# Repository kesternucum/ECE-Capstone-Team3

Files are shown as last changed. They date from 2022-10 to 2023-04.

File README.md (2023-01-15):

# Parking Lot Monitoring System

## Executive Summary

Commuter students at Tennessee Technological University in Cookeville, TN, frequently face difficulties to find open parking spots in lots during peak hours of the school day, which causes tardiness to class to be a common occurrence. Commuters typically have a lack of foreknowledge of the availability of parking spots across lots prior to entering campus. Due to current products on the market either being very expensive or not fully feasible or effective for Tennessee Tech’s parking lots, an in-house parking lot monitoring system designed by students in Tennessee Tech’s College of Engineering was proposed to provide a more cost-effective solution. A parking lot monitoring system has been designed to utilize sensor technology to track and frequently update the number of available parking spots so that students can know the occupancy of a parking lot in real-time. The data from the sensor technology would be displayed on a mobile application that students can download to view real-time statistics and previous history of parking lot occupancy, as well as on a ground-level display board. This project involves interdisciplinary collaboration between teams from the Department of Electrical and Computer Engineering and the Department of Computer Science while under the direction of the Naval Sea Systems Command (NAVSEA) in Dahlgren, VA.

## Capabilities

As a proof of concept, this project is focused on implementing a Parking Lot Monitoring System to track the number of available parking spots in the Red lot behind Bell Hall. The goals for the capabilities of this system are:
  * Utilize computer vision AI to determine the number of available parking spots from images that are sent from cameras installed around the Bell Hall lot
  * Track the number of cars inside the Bell Hall lot using pneumatic road tubes for validation of the measurements from the cameras and computer vision
  * Display the number of available parking spots on a mobile application that students can use
  * Display the number of available parking spots on a sign (similar to those at airport parking lots)

## Salient Outcomes

The most important outcomes of this project will be added here once the Parking Lot Monitoring System project has been implemented and tested.

## Project Demonstration & Images

A demonstration video and images of the project will be added here once the system has been implemented and tested.

## About Us

### Team

**Kester Nucum** is a senior Computer Engineering major at Tennessee Technological University with double minors in Music Performance and Honors. Kester's interests in Electrical and Computer Engineering include artificial intelligence, digital signal processing, and applications in radar and RF technology. He has spent two summers as an intern at Dynetics in Huntsville, AL, where he worked in modeling and simulation of foreign weapons threat systems, and he plans to obtain a Master's Degree in ECE prior to starting a career in the defense industry. For the Parking Lot Monitoring System project, Kester will be primarily focusing on the cameras in the primary data acquisition system, the hardware for the server, and the computer vision AI software. Outside of classes, Kester serves as the President of the Tennessee Gamma chapter of Tau Beta Pi, plays violin in the University Orchestra, and is active in University Catholic.

**Aaron Wilhite** is a senior Electrical Engineering major at Tennessee Technological University with a minor in Math. He spent the previous year at a co-op with EOSYS in Smyrna, TN doing custom system integration. During this co-op he gained experience in HMI design and PLC (Programmable Logic Controller) programming. For the Parking Lot Monitoring System project, Aaron will be primarily focusing on the sign subsystem. Outside of classes, Aaron spends most of his time rock climbing and camping.

**Gabriel Laboy** is a senior Computer Engineering major with a minor in Computer Science at Tennessee Technological University. His interests include digital systems, virtual reality (VR), and cyber security. He spent a whole year as a co-op at EOSYS located in Smyrna, TN, and later plans to pursue a Master's Degree in Computer Science in hopes of being a professor of university. Gabriel's role in the project will be working on the power for the primary data acquisition system and collaboration with the Computer Science (CSC) team to ensure successful operation of the mobile application with the server. He is also currently serving as the Vice Chair of the student chapter of the Institute of Electrical and Electronics Engineers (IEEE), and will serve as the Recording Secretary of the Tennessee Gamma chapter of Tau Beta Pi in the spring.

**Genevieve Schreiber** is a senior Computer Engineering major at Tennessee Technological University with a minor in Mathematics. Her interests involve FPGAs, embedded systems, and space. She has spent 1 year interning at ALTEN as a software intern working in embedded systems. She plans to work in space-adjacent fields post-graduation. For this Parking Lot Monitoring System, Genevieve will be primarily focused on the networks involved between the many devices used. She is also part of the Omega Phi Alpha national service sorority.

**Reggie Garza** is a senior electrical engineering major at Tennessee Tech University. Reggie's interest include robotics and automation. He has spent the last two years interning at ATC Automation in Cookeville,TN. There he has been part of a team of engineers and has contributed with the electrical design and programming of several machines. Reggie will be helping design the primary acquisition system and the secondary acquisition system.

### Faculty Supervisor

**Jesse Roberts** is a Lecturer in the Department of Electrical and Computer Engineering at Tennessee Technological University. He received both his Bachelor's and Master's Degrees in Electrical Engineering from Tennessee Tech, and he is currently working on obtaining his Doctorate of Philosophy in Computer Science from Vanderbilt University, anticipated May 2023. He is the instructor for the ECE 4961 Capstone I and ECE 4971 Capstone II courses at Tennessee Tech, and he serves as the faculty supervisor for the Parking Lot Monitoring System project. His research interests include Game Theory and Mechanism Design, Graph and Learning Theory, Spiking Neural Networks, Computational Sustainability, Computational Creativity and Criticism, and Automation. In his free time, Jesse loves to go rock climbing.

### Stakeholders

The **Naval Surface Warfare Center Dahlgren Division** in Dahlgren, VA, under the Naval Sea Systems Command, more commonly referred to as **NAVSEA**, is the primary customer of this project. The NSWC Dahlgren Site is a premier research and development center that serves as a specialty site for weapon system integration. Engineers and scientists focus on providing research, development, test and evaluation, analysis, systems engineering, integration, and certification of complex naval warfare systems related to surface warfare and strategic systems. NAVSEA engineers, builds, buys and maintains the ships, submarines, carriers (unmanned systems) and combat systems that patrol the oceans and secure American shores.

The major stakeholder that will be affected by this project are the **commuter students** of Tennessee Tech since this project is designed with them in mind. We hope that this project will help commuter students (students who drive to campus and possess a Red parking pass) plan out their parking routines more effectively and also know of alternate spots to park on campus, albeit if those spots are more inconvenient/out of the way.

Another major stakeholder is **Tennessee Tech** itself because the data collected from this system--the parking history of lots throughout the day--can be potentially used for future planning and zoning purposes. This data can prove to be valuable in collecting data about student parking behaviors since campus parking is an evergreen problem that persists at Tennessee Tech.

### Recognitions

We first would like to thank Kristen Voyles and Rob Sexton at NSWC Dahlgren for their mentorship about the engineering design process throughout the entire capstone process. Their feedback and advice were invaluable, not just for the project but for us as future engineers as well.

We would like to thank the Office of Parking and Transportation, University Police, and Facilities at Tennessee Tech for allowing to implement this project on campus. More recognitions to come!

Also, thank you to WUCT - News Talk 94.1/AM 1600 for featuring our project on your station! We are excited that the community is excited about our project. Go check out the news article here: ["TTU Capstone Students Working To Develop Program To Better Parking"](https://newstalk941.com/ttu-capstone-students-working-to-develop-program-to-better-parking/).

## Repo Organization

### Reports

All reports about the project holistically can be found in the [Reports](/Reports) folder. The major files in the Reports section are as follows:

1. [Project Proposal](/Reports/ProjectProposal.pdf)
2. [Conceptual Design and Planning](/Reports/Conceptual&#32;Design&#32;and&#32;Planning.pdf)
3. Final Report (to be added later)
4. Lessons Learned (to be added later)
5. Experimentation (to be added later)

### Documentation

All signoffs, electrical schematics, 3D models, and bill of materials (BOM) and other documentation such as images, the project datasheet, and project poster can be found in the [Documentation](/Documentation) folder. The major folders in the Documentation section are as follows:

1. [Signoffs](/Documentation/Signoffs)
  * Signoffs are written for each subsystem in which each subsystem's design is analyzed in light of the constraints to ensure their functionality prior to ordering their components. Signoffs once approved will be stored here.
2. [Electrical](/Documentation/Electrical)
  * The Electrical folder will contains two folders: [PCB](/Documentation/Electrical/PCB) and [Schematics](/Documentation/Electrical/Schematics). The PCB folder contains all designs for printed circuit boards (PCBs) that are custom built for this project. The Schematics folder contains all buildable wiring schematics for analog circuits designed for this project.
3. [Images](/Documentation/Images)
  * Images for the project, such as images of the project when built, images used for signoffs, etc.
4. [3D Models](/Documentation/3D&#32;Models)
  * Buildable 3D model schematics for each constructed system of the project.
5. Final Bill of Materials (to be added later)
  * All components ordered compiled to generate the total cost for building this project.
6. Datasheet (to be added later)
  * The datasheet includes all information necessary for other systems to interface with your project in the intended manner, such as the power expectations, interfacing, and compliance. The datasheet will also include results from all experimentation and the interpretation of the results.
7. Poster (to be added later)
  * Poster that is presented at the finale of Capstone II.

### Software

All software that has been programmed for this project will be stored in the [Software](/Software) folder.

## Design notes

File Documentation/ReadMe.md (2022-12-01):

# What should be in the documentation folder

## Signoffs

An important part of engineering is analysis. Designs must be analyzed to show that the subsystem is **likely** to function (sometimes things still don't work). This reduces the overall risk that a client or firm will have wasted money on a solution that was destined to fail. For information about what must be included in each signof file, refer to the readme file in the signoff directory.

A signoff must be completed and approved for each subsystem before the components for the subsystem may be ordered. Each of the signoff documents should be an appropriately named markdown file in the signoff directory.

## Final set of prints (final design artifacts)

All schematics and artifacts should be in an appropriate file type.

### 3D Models

Required format:
- .stl

3D models should be stored in the proper file type to facilitate editing, viewing, and printing. The best filetype for this is .stl, so all 3d models should be pushed to the repo as stl files. Stl files can be converted to solidworks models or autocad 3d models as necessary, can be 3d printed easily, and are 3d viewable natively in github. File (Documentation/3D Models)

Every constructed system of the project must have a complete (buildable) 3d model schematic.

### Wiring Schematics

Required software:
- autocad or autocad electrical

For wiring schematics, use autocad or autocad electrical. All the source files must be included in the github repo along with pdf versions of all schematics. File (Documentation/Electrical/Schematics/Sources)

Every electrical system must have a complete (buildable) pdf circuit schematic. File (Documentation/Electrical/Schematics)

Autocad is freely available to students with versions for mac, windows, and linux.

#### PCB files

Required Software:
- kicad

KiCad should be used for all PCB design. All source files must be deposited in the repo. File (Documentation/Electrical/PCB/Sources)

Along with the source files, a complete set of gerber files for each PCB must also be included in the repo. These should be included in a folder called gerber files. File (Documentation/Electrical/PCB)

kiCad is a free and open source software.

## Final BOM

The final version of the BOM should be uploaded as a pdf output of the excel BOM file. The excel BOM file should also be included.

## Datasheet

This must give all the information necessary for other systems to interface with your project in the intended manner. This must include the power expectations, interfacing, and compliance.

This must also include the results from all experimentation and the interpretation of the results.

## The project poster

Include the project poster

## Detailed photos of the project

Include a folder of a set of detailed photos of the project. File (Documentation/Images)

## Any additional documents that are appropriate to include

If there are additional items that are important to understanding and working on or with the project, include them as well.

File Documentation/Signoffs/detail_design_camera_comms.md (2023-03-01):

# Camera Communications Detail Design

## Function of Subsystems

The camera communications subsystem allows each camera to connect to the university's Wi-Fi network so that the images collected from each camera can be transmitted wirelessly to the remote server for AI image processing.

## Constraints

1. The Avigilon cameras have only Ethernet (RJ45) inputs and therefore require an adapter to connect to the Wi-Fi network, so the chosen adapter must be able to communicate back and forth between Ethernet (RJ45) and Wi-Fi.

2. This device must have the ability to establish a reliable and stable wireless connection to the Wi-Fi network in Bell Hall from its camera position. This device should be able to connect to Wi-Fi at a range of 100 m, which is the distance from Bell Hall to the southeast corner of the parking lot.

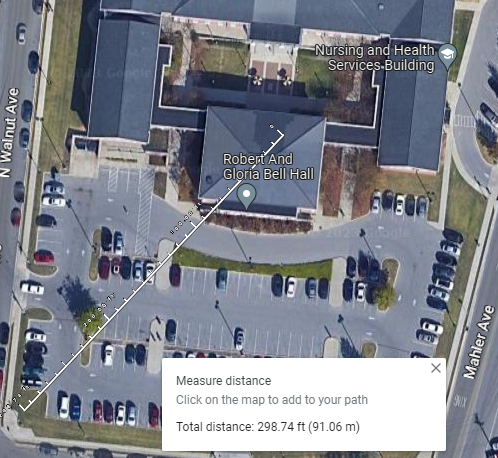
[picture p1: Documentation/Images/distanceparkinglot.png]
Figure 1. Distance Measurement between Cameras and Building
 

3. This device must be able to transmit frames at a resolution of 1080p (the resolution of the Avigilon cameras) at a frame rate of 30 fps (the rate of the Avigilon cameras). To stream a YouTube video at a 1080p resolution with a standard frame rate of 30 fps, a bitrate setting of 8 Mbps is recommended [1]. Thus, the Ethernet-to-WiFi converter adaptor must be able to transmit data at a rate of at least 8 Mbps.

# Buildable Schematic

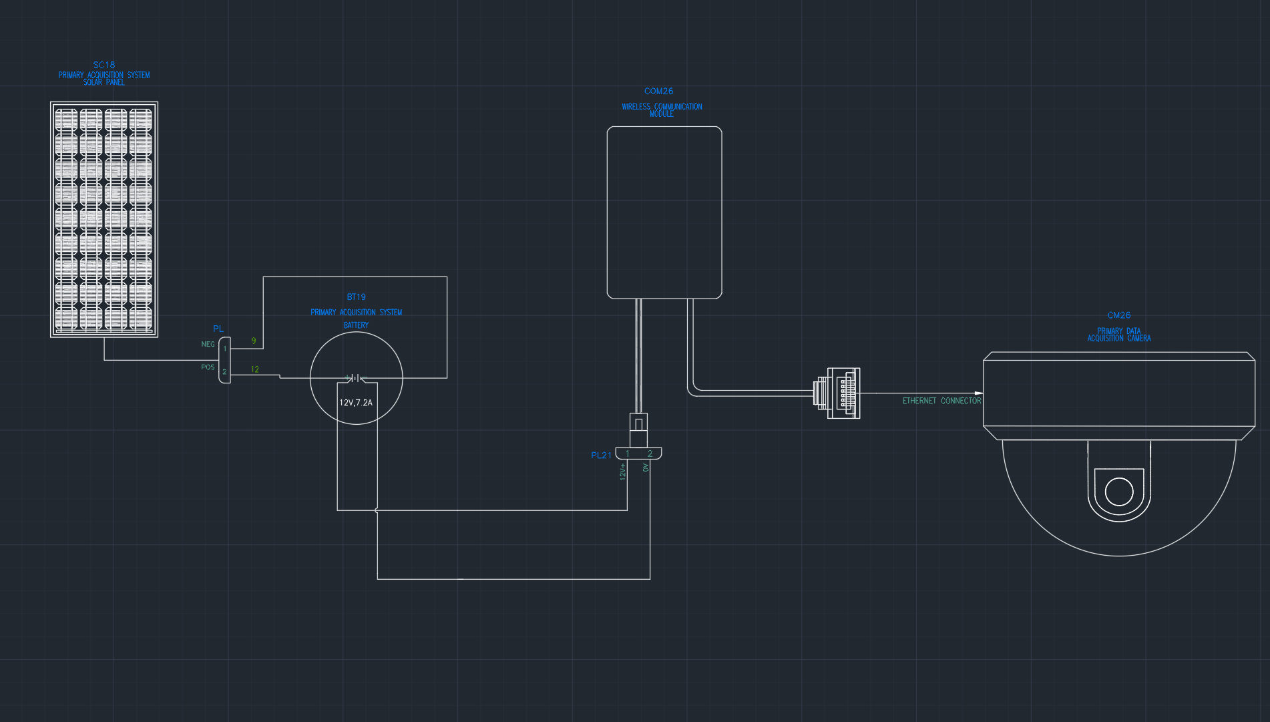
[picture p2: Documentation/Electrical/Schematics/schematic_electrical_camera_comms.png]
Figure 2. Wiring Diagram for Vonets VAP11G-50 Wi-Fi Bridge/Repeater


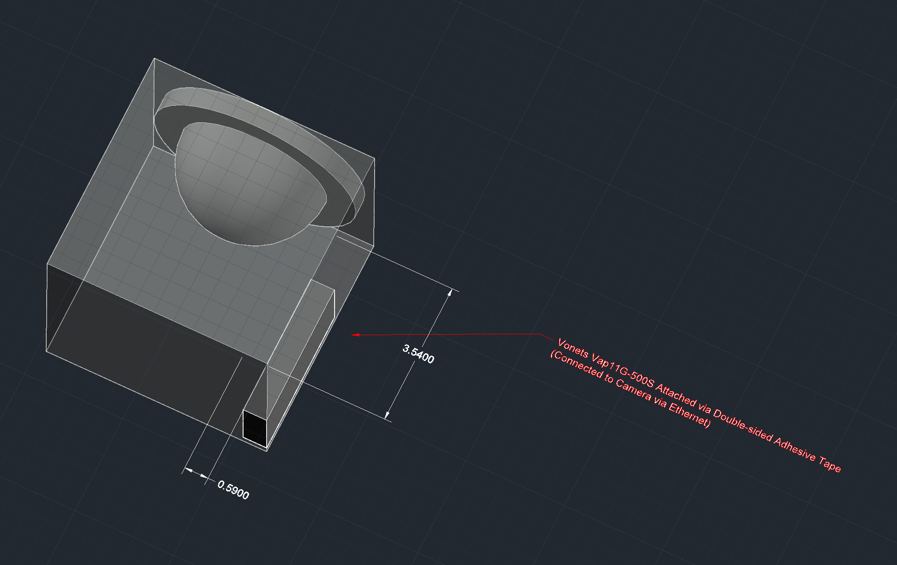
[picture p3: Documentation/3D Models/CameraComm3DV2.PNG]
Figure 3. Camera Communications 3D Schematic

<div align="center"> Figure 3. Camera Communication Module 3D Placement Schematic
<br />
<div align="left">

Note: The Module will be attached to the interior of the casing using a double sided adhesive tape.

## Analysis

Selected Adapter: Vonets VAP11G-500S Wi-Fi Bridge/Repeater

1. Ethernet-to-WiFi Adaptor
  - The VAP116-500S Wi-Fi Bridge/Repeater has an ethernet cable that can be connected to the Avigilon cameras (which can either be used for power over ethernet or transmission via ethernet, if no power is available).

2. Network Capabilities
  - The device has a transmission rate of 300 Mbps, which is well above the needed streaming rate of 8 Mbps.

3. Range
  - The ethernet-to-WiFi converter has a unobstructed range of 200 m unobstructed and obstructed of 100 m, which are both well-above the maximum range of 85 m needed to reach routers in Bell Hall.

## Bill of Materials

| Name of Item | Description | Used in which subsystem(s) | Part Number | Manufacturer | Quantity | Unit Price | Total |
| --- | --- | --- | --- | --- | --- | --- | ----- |
| VONETS VAP11G-500S WiFi to Ethernet Converter | WiFi Bridge 2.4GHz WiFi Repeater/Point to Point with RJ45 Male DC/USB Powered for PLC IP Camera Printer Medical Devices Network Device | Primary Data Acquisition | VAP11G-500S | Vonets | 2 | $37.98 | $37.98 |
| | | | | | | | **$75.96** |

Link to Purchase: [Purchase Link](https://www.amazon.com/%E3%80%90Upgraded-VAP11G-500S-Industrial-High-Power-Application/dp/B0B8ND6MQL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)
 
## Cited Sources

[1] [https://golightstream.com/what-is-video-bitrate/](https://golightstream.com/what-is-video-bitrate/)

# Revisions

2/15/2023 - Reformatted and reworked sign off with different Ethernet-to-WiFi adaptor

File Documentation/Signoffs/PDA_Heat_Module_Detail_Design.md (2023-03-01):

# Primary Data Acquisition Heat Module Detail Design

## Big Picture

The primary data acquisition will use cameras designed for indoor use, but in an outdoor setting. Therefore, a few more additional constraints must be addressed in order to ensure the cameras don’t malfunction during operation. This document addresses temperature control of the cameras to ensure the camera’s specified operation temperature is not exceeded.

## Specifications

Existing Hardware Constraints

1. Avigilon Cameras [1]
    * Operating Temperature: -10 °C to +50 °C (14 °F to 122 °F)

Reliability Constraints

1. Any device installed should last long enough to not require frequent replacement
2. Installed devices should not interfere with camera vision and operation
3. The temperature control element should only operate when the appropriate environmental temperature has been reached

## Buildable Schematic

Heat_Module_Connections

Figure 1. Hardware Electrical Connections

## Analysis

Environmental Temperatures

1. The average range of temperature within Cookeville for the year usually goes between 28 °F to 88 °F with it rarely going lower than 12 °F and higher than 94 °F [2]. The lowest and highest temperature ever recorded in Cookeville are -22 °F and 105 °F, respectively [3]. This means there is no concern for cooling the cameras given it has a max operating temperature of 122 °F, but they must be warmed up in the winter due to the minimum operating temperature of 14 °F [1].

Collecting Temperature Data

1. In order to get the current temperature, it has been decided to get information via a local weather station in Cookeville, TN. The server subsystem will get the temperature and send it to an Arduino Nano 33 IoT. This Arduino is capable of connecting to WiFi [4], so it should be able to receive information from the server once connected. The Arduino is also small (45 x 18 mm) and lightweight (5 g) [4], so it should not occupy a significant amount of space within the primary data acquisition system casing.

Heating the Environment

1. To heat the environment around the camera, it has been decided to go with a film heating plate. The films can reach temperatures of up to 80 °C (176 °F) [6] which should be plenty of heat to keep the surrounding environment of the camera warm. They are also small (30 x 40 mm) and lightweight (0.634 oz), and feature an adhesive side [6] which should make attachment to the casing of the primary data acquisition system simple.

Powering the Heating Element

1. To make sure that the heater plate only provides heat when needed, there will be a connection made between one of the Arduino digital pins and the heat plate mediated by a transistor. The transistor will act as a switch allowing power to be delivered to the heat plate from the power supply as seen in Figure 1 of the buildable schematic section. The Arduino will be programmed to source voltage to the transistor from its digital pin when a cold enough is read and keep sourcing voltage to the transistor for one minute before shutting off the digital pin. After a two minute delay, the Arduino will check the temperature again and repeat the powering process if needed.
2. The chosen transistor is an N-MOS transistor with the needed features to be compatible with both the Arduino and power supply.
    * A VDSS of 55 V and 47 A [8] which is far above the 5 V and 200 mA requirement to power the heat plate [6].
    * A VGS(th) of 1 V [8] which should meet the constraint of the 1.8-3.3 V output of the Arduino digital pin [5].

Addressing Risks

1. Condensation is a major concern given that the heating element will get very hot and operate around freezing temperatures. Proper ventilation of the primary data acquisition casing, though, will be handled by the ME team.
2. Protection of the arduino and heating plate from the weather will be handled in the casing subsystem design.

Important Notes

1. The BoM does not accurately reflect what will be purchased, but instead how much the system would need given the original outline of the project.

## Bill of Materials

| Name of item | Description | Subsystem | Part Number | Manufacturer | Quantity | Price | Total |
|---|---|---|---|---|---|---|---|
|Arduino Nano| Arduino Nano 33 IoT | Primary Data Acquisition | ABX00027 | Arduino | 7 | $24.00 | $168.00 |
|Transistor| MOSFET N-CH 55V 47A | Primary Data Acquisition | IRLZ44NPBF-ND | Infineon Technologies | 7 | $1.52 | $10.64 |
|Film Heater Plate| 5V 1W Flexible Polymerize Heater Film Stripboard Mat 30mmx40mm | Primary Data Acquisition | Number Not Found | Icstation | 2 | $15.99 | $31.98 |
| Total | | | | Total Components | 16 | Total Cost | $210.62 |

## Revisions

**02/11/2023**

Updated constraints requirement.

Removed invalid buildable schematic.

Changed method of temperature detection.

Created a Bill of Materials.

**02/20/2023**

Updated analysis to detail how the subsystem will get weather status.

Updated analysis to address being able to power the heat module.

Changed device used to communicate to server and power on heating element.

Update Bill of Materials.

**02/28/2023**

Updated big picture to more accurately reflect intent of design.

Updated constraints to more accurately reflect intent of design.

Updated analysis to make it more readable and added electrical analysis.

## Cited Sources

[1] “2.0 Megapixel Day/Night H.264 HD Indoor Dome Camera,” _AVIGILON_, 2013.  https://www.securityinformed.com/datasheets/avigilon-2-0-h3-d1-ip-dome-camera/co-3126-ga/2.0-H3-DdatasheetEN2.pdf.

[2] “Climate and Average Weather Year Round in Cookeville,” _Weather Spark_, 2023. https://weatherspark.com/y/15151/Average-Weather-in-Cookeville-Tennessee-United-States-Year-Round.

[3] “Cookeville Weather Records,” _Extreme Weather Watch_, 2022. https://www.extremeweatherwatch.com/cities/cookeville.

[4] “Arduino Nano 33 IoT,” _Arduino Store_, 2023. https://store-usa.arduino.cc/products/arduino-nano-33-iot.

[5] “V[oltage on digital output pins depending on voltage source?](https://forum.arduino.cc/t/voltage-on-digital-output-pins-depending-on-voltage-source/686526),” _Arduino Forum_, Dec 2020. https://forum.arduino.cc/t/voltage-on-digital-output-pins-depending-on-voltage-source/686526/2.

[6] “4 PCS Film Heater Plate Adhesive Pad, Icstation PI Heating Elements Film 5V 1W Flexible Polymerize Heater Film Stripboard Mat 30mmx40mm,” _amazon.com_, 2023. https://www.amazon.com/5V-Flexible-Polyimide-Heater-Plate/dp/B0727X2DGC/.

[7] “IRLZ44NPBF,” _Digi-Key_, 2023. https://www.digikey.com/en/products/detail/infineon-technologies/IRLZ44NPBF/811808.

[8] “IRLZ44NPbF,” _International Rectifier_, 11 Nov 2003. https://www.infineon.com/dgdl/irlz44npbf.pdf?fileId=5546d462533600a40153567217c32725.

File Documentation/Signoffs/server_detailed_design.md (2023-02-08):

# Detailed Design for Hardware of Server

## Function of the Subsystem
The server can be likened to the heart of the entire parking lot monitoring system, in which the server receives input data from the sensors, processes the data, and then send the data to be stored in a Firebase remote server. The server communicates with the Primary and Secondary Data Acquisition Systems, and it will have an AI application to process images from the Primary Data Acquisition System cameras to determine the number of cars in the parking lot. The server will also have a program to store the count from the road tubes in the Secondary Data Acquisition system, determine the accuracy of the counts between the Primary and Secondary systems, and calculate parking histories and averages.

## Constraints

Many of these constraints were determined first by researching the hardware needed for a full-scale surveillance system with 7 cameras (which will constantly provide video feed) and by determining the computational costs and speed to optimally run a computer vision image processing application that is adequate for our needs. However, a surveillance system requires much more processing power than what we need, so a surveillance system is treated as an ideal for our system.

In addition, the server will be designed to use the YOLO object detection algorithm. The YOLO (You-Only-Look-Once) Algorithm is a popular real-time object detection algorithm that is used in vehicle detection applications such as [1]. YOLO is a deep learning-based approach that can predict an object's class/category (what kind of object is it), bounding box (a box that encompasses the object), and probability inside bounding box, for multiple objects in a frame [2]. YOLOv4 is the latest version of the algorithm, featuring many improvements from its predecessor versions. Although YOLO is known for its high performance, it is very resource-intensive since it does run a deep neural network. On an AMD Ryzen 7 CPU on the Windows platform, YOLO only produces an image processing rate of 2.5 fps, but on a Nvidia GPU in the Linux platform, YOLO can process up to 45 fps [1]. Because the mobile application must update data at a minimum of every second (since this rate will provide enough of a real-time feel to users), the 5 cameras that track the statically tracked lots will only have one processed image every minute. For the dynamically tracked lots, since a minimum image rate of 5 fps is needed to capture at least 2 or 3 images to capture a moving car's motion and determine its direction (edge case is a fast-moving car at 25 mph), each of those cameras will send 5 images to the server per second, i.e. every 6th image. Thus, 5 cameras sending 1 image every minute with 2 cameras sending 5 images per second makes a minimum of 15 images to be processed within a second. The YOLO algorithm will be run on the GPU and primarily influence GPU constraints.

There are two frameworks that will either be used to run the YOLO algorithm. The first is OpenCV, which is a free, open-source library for computer vision applications that has been used extensively throughout industry. It is known for its high performance (as compared with other frameworks like TensorFlow) and its extensive documentation, providing a relatively easy learning experience for beginners. The hardware requirements for OpenCV are listed as according to their influence on certain computer parts. OpenCV (3.4.2 at minimum) has options to use enable CUDA for faster YOLO performance with GPU acceleration, though OpenCV is primarily CPU intensive [3]. The other framework is Darknet, which was made specifically for YOLO but runs only on Linux [4]. Darknet can also be used with OpenCV and CUDA dependencies as well. The computer components will be selected based off being able to support either of these frameworks, which should have similar constraints.

The server must also be able to run the Linux operating system due to the versatility of Linux as compared with Windows or MacOS for the needed programming power with the video feeds and AI applications.

1. CPU
  * The processor must be powerful enough to perform tasks such as determining the number of vehicles present in a parking lot via AI analyzing images sampled from multiple cameras and via keeping track of counts from road tubes and compiling statistical data and history about parking availability. For a surveillance system, it is recommended to have one thread per camera, which for this system means 7 threads (which can be provided in 4 double-threaded cores). Thus, the CPU needs at least 6 double-threaded cores which allows half of the threads to be devoted to obtaining images from the cameras and the other half for processing the images, processing road tube counts, and sending the processed data to the server. For live streaming applications, a frequency of 3.0 GHz is required for 1080p streaming (1080p is the intended resolution of the camera feeds) [5].
  * OpenCV can be run a laptop with a processor as "low" as an Intel Core Duo with a frequency of 1.83 Hz paired with 2 GB of RAM [6]. Since the YOLO algorithm will run primarily on the GPU, [6] provides a minimum baseline of what OpenCV needs to run, which is a minimum of 2 cores each with 1 thread. However, [3] tested YOLOv4 with CUDA-enabled OpenCV on a computer with an Intel Core i5 7300HQ CPU and a Nvidia GTX 1050 Ti GPU, and although the i5 7300HQ produced only 2.1 fps, the CPU for our system must match or exceed the performance of this CPU.

2. GPU
  * Since GPUs are typically used for AI/deep learning applications, the GPU will be mainly used to run the computer vision algorithm that processes the images from the cameras.
  * To run the YOLO algorithm, a Nvidia GPU is needed. [3] tested YOLOv4 with CUDA-enabled OpenCV on a computer with an Intel Core i5 7300HQ CPU and a Nvidia GTX 1050 Ti GPU. Running on the i5 7300HQ produced only 2.1 fps whereas the GTX 1050 Ti produced 20.1 fps. Thus, the GPU must match or exceed the performance of a GTX 1050 Ti.

3. RAM
  * It is recommended to have at least 4 GB RAM to run the OpenCV AI library [8]. In addition, for a surveillance system, 16 GB of RAM is recommended for 8-10 cameras [9]. However, because we are not live streaming, 16 GB should be sufficient for image collection and processing using the OpenCV AI library.

4. Storage
  * For the storage, two different storage drives are needed to ensure the highest efficiency when storing collected data and system data. A small SSD (128 GB) shall be used to store the boot of OS, which has been determined to be Linux, to increase the speed of the server. This is considered good practice for PCs/servers. In addition, since no images are being stored on the server, the server does not need a lot of storage, so 2 TB should be sufficient.

5. Power Supply
  * Since this server will be running 24/7, the Power Supply will need to be at minimum an 80 Plus Gold Rating, which is considered a sweet spot for price-performance (i.e. most cost-effective) [10]. Also, the power supply should be able to supply at least the estimated wattage of all the parts, as determined when entering the selected parts in PCPartPicker [11]. The power supply will also need to be suitable to be plugged into a typical American wall outlet with 120 V. The power supply should also have a high mean time between failures (MTBF) since this server is to be built as if it were to run for years without failure.

6. Motherboard
  * The motherboard must be able to fit the CPU, GPU, RAM, storage drives, and Wi-Fi adapter. The motherboard must be compatible with the CPU processor (i.e. supports AMD if an AMD processor is used), and the socket must be up-to-date with other current popular models (i.e. AM4). Ideally the size of the motherboard should be ATX so that the server could be easily built without worrying about size constraints. The motherboard could have an embedded LAN chip for Wi-Fi; however, this is not required, as long as the motherboard is able to have a Wi-Fi adapter attached.

7. Case
  * The case must be able to house the CPU, GPU, RAM, storage drives, Wi-Fi adapter, and cooler for the CPU. The case must also have or be able to have at least 2 or 3 fans as well as good filters so that the entire server could have proper airflow and could prevent accumulation of dust.

8. Wi-Fi Adapter
  * Because the system will have to communicate wirelessly via Wi-Fi with the cameras, sign, and mobile application, a Wi-Fi adapter is needed. The server needs to be able to obtain images from the cameras of the Primary Data Acquisition System and vehicle counts from the road tubes of the Secondary Data Acquisition System. In addition, the server needs to be able to output the current available parking count (processed data) to the remote Firebase server and to the outdoor signage. All of the hardware will not be physically connected to the server, hence the server’s needs for wireless communication via Wi-Fi.
  * Because the server will be connected to cameras, the current cameras that have been selected to be used to implement the Primary Data Acquisition System have a resolution of 1080p (active pixels are 1920 x 1080) and a frame rate of 30 fps, which imputes a minimum bit rate of 4541 kbps (kbits/s), or 4.541 Mbps (Mbits/s) [12]. Because at least a 30-40% buffer is ideal to have to account for fluctuations in upload speeds since the server will be receiving data constantly [13], at least 6.3 Mbps should be accounted for per camera, meaning that for a 7-camera system, a minimum bit rate of 44.1 Mbps is required.

9. CPU Cooler
  * Since the server will be running 24/7 and will be doing very heavy computations due to the number of video feeds being inputted and the amount of processing required for the AI algorithm and the mobile application queries, to prevent the CPU from overheating, a cooling mechanism is needed. The CPU cooler must be able to be fitted into the case.

In addition, all parts must be compatible with each other in terms of socket size, form factor, etc.

## Buildable Schematic

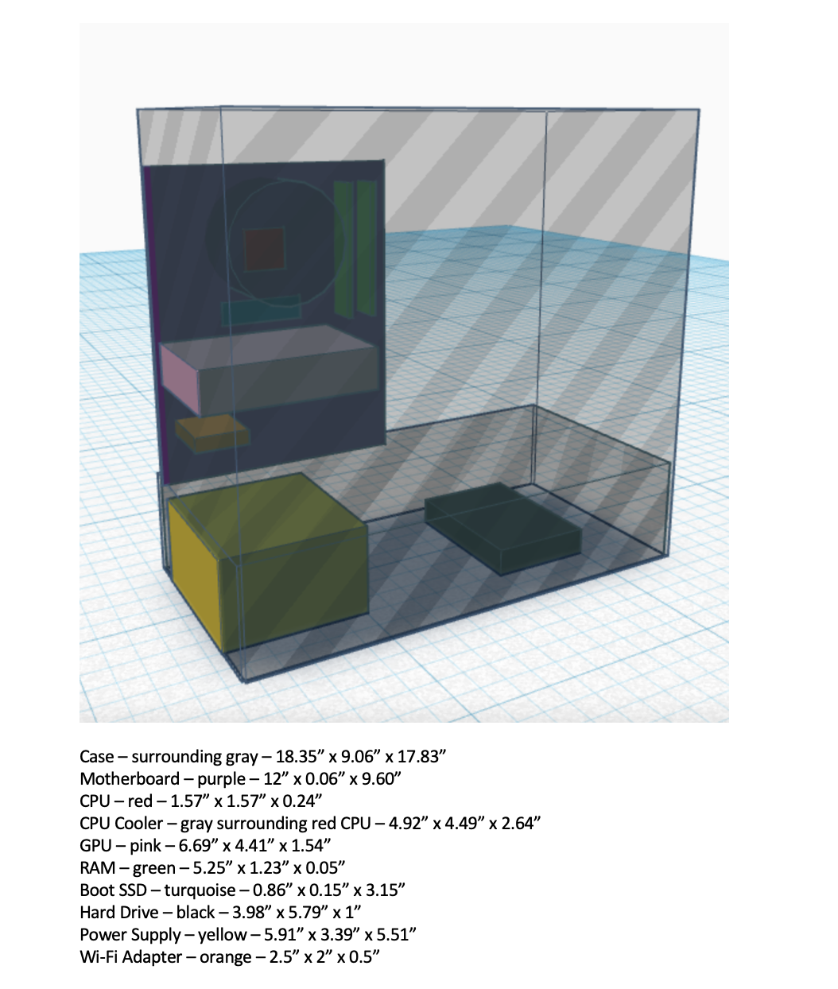
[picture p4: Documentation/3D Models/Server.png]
Figure 1. Server Components within Case

<div align="center"> Figure 1. Server Components within Case
<div align="left">

## Analysis

When selecting these parts, these parts were entered into PCPartPicker to ensure all parts listed below are compatible, in which the build can be viewed at [11]. Form factors, socket sizes, etc. have been examined to also ensure compatibility.

1. CPU
  * Selected Part: AMD Ryzen 5 3600 6-Core, 12-Thread Unlocked Desktop Processor with Wraith Stealth Cooler
    - The AMD Ryzen 5 3600 meets the specifications listed above. This CPU has 6 cores and 12 threads, a base clock frequency of 3.6 GHz, a maximum frequency of 4.2 GHz, and a maximum frequency of 4.6 GHz.
    - Purchasing this CPU from Amazon comes with its own cooling unit.
    - The AMD Ryzen 5 3600 also has a better performance especially in terms of speed as compared with the Intel i5 7300HQ used as a minimum CPU marker [14].
    - The AMD Ryzen 5 3600 has an AM4 socket size, which matches that of the Gigabyte B550 motherboard.

2. GPU
  * Selected Part: PNY GeForce GTX 1650 4GB GDDR6 Dual Fan Graphics Card
    - The GTX 1650 GPU meets the specifications listed above. This GPU uses NVIDIA Turing architecture.
    - The GTX 1650 also has a better performance especially in terms of speed as compared with the GTX 1050-Ti used as a minimum GPU marker [15].
    - The graphics card requires a PCIe x16 slot to be fitted onto the motherboard, in which the Gigabyte B550 motherboard has two PCIe x16 slots.

3. RAM
  * Selected Part: CORSAIR Vengeance LPX 16GB (2 x 8GB) 288-Pin PC RAM DDR4 3200 (PC4 25600) Desktop Memory Model
    - The Corsair DDR4 RAM meets the specifications listed above. This RAM has 16 GB of RAM, which is enough to handle the image collection and processing from all cameras and the other applications the system will need to perform.
    - The RAM requires DDR4 sockets to be fitted onto the motherboard, and the Gigbayte B550 motherboard does have four DDR4 sockets for both RAM sticks to be inserted in.

4. Storage
  * Selected Part for Boot Drive: Team Group MP33 M.2 2280 128GB PCIe 3.0 x4 with NVMe 1.3 3D NAND Internal Solid State Drive (SSD)
    - The Team Group SSD meets the specifications listed for the boot drive SSD since it meets the storage requirements of 128 GB.
    - The Gigabyte B550 motherboard has an M.2 port for the SSD drive to be fitted onto.
    - The Linux OS software can be loaded onto Team Group 128 GB SSD in the server via a USB flash drive once this computer has been fully built.
  * Selected Part for Storage Drive: Seagate BarraCuda 2TB Internal Hard Drive HDD – 3.5 Inch SATA 6Gb/s 7200 RPM 256MB Cache 3.5-Inch
    - The Seagate BarraCuda Hard Drive meets the specifications listed for the storage drive since it has 7200 rpm as well as 2TB for storage.
    - The Corsair 4000D case has two 3.5 inch HDD trays in which the hard drive can be fitted onto. The second HDD tray also allows for more storage could be added in the future if needed.

5. Power Supply
  * Selected Part: Thermaltake Toughpower GX1 80+ Gold 500W SLI/CrossFire Ready Continuous Power ATX 12V V2.4/EPS V2.92 Non Modular Power Supply
    - The Thermaltake Toughpower GX1 Power Supply meets the specifications listed above since the estimated wattage of all of the selected parts according to PCPartPicker is 254 W [11]. This power supply is 500 W and 80 Plus Gold certified, and it has a MTBF of 100,000 hours as well as an input voltage of 100 V to 240 V.
    - The power supply has an ATX form factor, which is the same as the Corsair case, so the Thermaltake Toughpower GX1 power supply will fit in the Corsair 4000D case. The Gigabyte B550 is also ATX, so the power supply and motherboard are compatible with each other.
    - Buying a power supply comes with all the standard cables needed for completing a computer. This is a standard in power supply packaging.

6. Motherboard
  * Selected Part: GIGABYTE B550 GAMING X V2 AM4 AMD B550 SATA 6Gb/s USB 3.0 ATX AMD Motherboard
    - The Gigabyte B550 Motherboard meets the specifications listed above.
    - The Gigabyte B550 motherboard has an AM4 socket, in which the AMD Ryzen 5 3600 can be inserted onto. The Wraith Stealth CPU cooler is also compatible with AM4.
    - This motherboard also has an ATX form factor, which matches that of the Corsair case and the Thermaltake Toughpower power supply. Thus, the motherboard will fit in the selected case and is compatible with the power supply.
    - It also has three PCIe x1 slots and two PCIe x16 slots, in which the Wavlink Wi-Fi adapter and the GTX 1650 GPU can be inserted into, respectively.
    - It also has four DDR4 sockets which can support both Corsair Vengeance RAM sticks.
    - The motherboard has an M.2 port for the Team Group SSD.

7. Case
  * Selected Part: Corsair 4000D Airflow CC-9011200-WW Black Steel / Plastic / Tempered Glass ATX Mid Tower Computer Case
    - The Corsair 4000D case meets the above specifications by having enough space to fit all components and by having two fans for airflow. The buildable schematic in Figure 1 shows how all of the listed selected parts can fit in this case.
    - The case has an ATX form factor, which matches that of the Gigabyte B550 motherboard and the Thermaltake Toughpower GX1 power supply, which means that the motherboard and the power supply will fit in the case.
    - The case also has two 3.5 inch HDD trays, in which one can house the Seagate BarraCuda hard drive.

8. Wi-Fi Adapter
  * Selected Part: Wavlink AX3000 Wifi 6 PCIe WiFi Card Bluetooth 5.2 Tri-band 2.4G/5G/6G Network Card 802.11ax,Up to 3000Mbps WiFi Network Card with MU-MIMO, OFDMA, Heat Sink, for Desktop PC Support Windows 11,10 64bit
    - The Wavlink AX3000 Wi-Fi Adapter meets the above specifications since it can accommodate up to 3000 Mbps.
    - The Wavlink AX300 Wi-Fi adapter requires a PCIe x1 slot, in which the Gigabyte B550 motherboard has three PCIe x1 slots (two of which will be accessible once the GPU is placed onto the motherboard). It also has a cable that plugs directly into the motherboard for power and data transmission.

9. CPU Cooler
  * Selected Part: Wraith Stealth Cooler
    -  The AMD Ryzen 5 3600 Processor comes with its own Wraith Stealth Cooler which fits over the CPU. The Wraith Stealth Cooler is also compatible with every AM4 motherboard, just like the one selected.

## BOM

| Name of Item | Description | Used in which subsystem(s) | Part Number | Manufacturer | Quantity | Unit Price | Total |
| --- | --- | --- | --- | --- | --- | --- | ----- |
| AMD Ryzen 5 3600 Processor | 6-Core, 12-Thread Unlocked Desktop Processor with Wraith Stealth Cooler | Server | 100-100000031BOX | AMD | 1 | $111.44 | $111.44 |
| PNY GeForce GTX 1650 Graphics Card | 4GB GDDR6 Dual Fan GPU | Server | GV-N1630OC-4GD | PNY | 1 | $189.99 | $189.99 |
| CORSAIR Vengeance LPX 16GB (2 x 8GB) RAM |  288-Pin PC RAM DDR4 3200 (PC4 25600) Desktop Memory Model | Server | CMK16GX4M2B3200C16R | Corsair | 1 | $48.98 | $48.98 |
| Team Group 128GB SSD | MP33 M.2 2280 128GB PCIe 3.0 x4 with NVMe 1.3 3D NAND Internal SSD | Server | TM8FP6128G0C101 | Team Group | 1 | $17.99 | $17.99 |
| Seagate BarraCuda 2TB Internal Hard Drive |  3.5 Inch SATA 6Gb/s 7200 RPM 256MB Cache 3.5-Inch HDD | Server | ST2000DM008 | Seagate | 1 | $49.99 | $49.99 |
| Thermaltake Toughpower GX2 80+ Gold 600W Power Supply | 500W SLI/CrossFire Ready Continuous Non Modular Power Supply | Server | PS-TPD-0500Nnfagu-1 | Thermaltake | 1 | $59.99 | $59.99 |
| GIGABYTE B550 GAMING X V2 ATX AMD Motherboard | AM4 AMD B550 SATA 6Gb/s USB 3.0 Motherboard | Server | B550 | Gigabyte | 1 | $129.99 | $129.99 |
| Corsair 4000D ATX Mid Tower Computer Case | Airflow Black Steel / Plastic / Tempered Glass Case | Server | CC-9011200-WW | Corsair | 1 | $104.99 | $104.99 |
| Wavlink AX3000 WiFi Network Card |Wifi 6 PCIe WiFi Card Bluetooth 5.2 Tri-band 2.4G/5G/6G Network Card 802.11ax,Up to 3000Mbps with MU-MIMO, OFDMA, Heat Sink, for Desktop PC Support Windows 11,10 64bit Wi-Fi Adapter | Server | 675X2 | Wavlink | 1 | $61.99 | $61.99 |
| | | | | | | | **$775.35** |

## Links to Purchase Parts

AMD Ryzen 5 3600 CPU:
[https://www.amazon.com/AMD-Ryzen-3600-12-Thread-Processor/dp/B07STGGQ18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](https://www.amazon.com/AMD-Ryzen-3600-12-Thread-Processor/dp/B07STGGQ18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)

PNY GeForce GTX 1650 4GB GDDR6 Dual Fan Graphics Card: [https://www.amazon.com/PNY-GeForce-1650-GDDR6-Graphics/dp/B08C7VTFQ8/ref=psdc_284822_t3_B01M360WG6](https://www.amazon.com/PNY-GeForce-1650-GDDR6-Graphics/dp/B08C7VTFQ8/ref=psdc_284822_t3_B01M360WG6)

CORSAIR Vengeance LPX 16GB (2 x 8GB) 288-Pin DDR4 RAM: [https://www.newegg.com/corsair-16gb-288-pin-ddr4-sdram/p/N82E16820233867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](https://www.newegg.com/corsair-16gb-288-pin-ddr4-sdram/p/N82E16820233867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)

Team Group 128GB M.2 SSD: [https://www.newegg.com/team-group-mp33-128gb/p/N82E16820331414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](https://www.newegg.com/team-group-mp33-128gb/p/N82E16820331414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)

Seagate BarraCuda 2TB Internal Hard Drive: [https://www.amazon.com/Seagate-BarraCuda-Internal-Drive-3-5-Inch/dp/B07H2RR55Q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](https://www.amazon.com/Seagate-BarraCuda-Internal-Drive-3-5-Inch/dp/B07H2RR55Q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)

Thermaltake Toughpower GX2 80+ Gold 500W Power Supply: [https://www.amazon.com/Thermaltake-Toughpower-Crossfire-Continuous-PS-TPD-0600NNFAGU-2/dp/B087CDR14Z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](https://www.amazon.com/Thermaltake-Toughpower-Crossfire-Continuous-PS-TPD-0600NNFAGU-2/dp/B087CDR14Z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)

GIGABYTE B550 ATX AMD Motherboard: [https://www.newegg.com/gigabyte-b550-gaming-x-v2/p/N82E16813145255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](https://www.newegg.com/gigabyte-b550-gaming-x-v2/p/N82E16813145255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)

Corsair 4000D ATX Mid Tower Computer Case: [https://www.newegg.com/black-corsair-4000d-airflow-atx-mid-tower/p/N82E16811139156](https://www.newegg.com/black-corsair-4000d-airflow-atx-mid-tower/p/N82E16811139156)

Wavlink AX3000 Wifi Network Card: [https://www.newegg.com/wavlink-690a5d-usb-3-0/p/0XM-00B5-00053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](https://www.newegg.com/wavlink-690a5d-usb-3-0/p/0XM-00B5-00053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)

## Cited Sources

[1] Z. Rahman, A. Ami, M. A. Ullah, "A Real-Time Wrong-Way Vehicle Detection Based on YOLO and Centroid Tracking," 2020 IEEE Region 10 Symposium (TENSYMP), 5-7 June 2020, Dhaka, Bangladesh. [https://arxiv.org/pdf/2210.10226.pdf](https://arxiv.org/pdf/2210.10226.pdf).

[2] J. Lentin. "A Gentle Introduction to YOLO v4 for Object detection in Ubuntu 20.04," _Robocademy_. [https://robocademy.com/2020/05/01/a-gentle-introduction-to-yolo-v4-for-object-detection-in-ubuntu-20-04/](https://robocademy.com/2020/05/01/a-gentle-introduction-to-yolo-v4-for-object-detection-in-ubuntu-20-04/).

[3] A. James. "Faster YOLOv4 Performance with CUDA enabled OpenCV," _Toward Data Science_, 24 Feb. 2021. [https://towardsdatascience.com/yolov4-with-cuda-powered-opencv-dnn-2fef48ea3984](https://towardsdatascience.com/yolov4-with-cuda-powered-opencv-dnn-2fef48ea3984).

[4] S. Canu, "YOLO object detection using OpenCV with Python," _Pysource_. [https://pysource.com/2019/06/27/yolo-object-detection-using-opencv-with-python/](https://pysource.com/2019/06/27/yolo-object-detection-using-opencv-with-python/).

[5] P. Richards, “What Type of Computer Do I Need to Live Stream?,” _StreamGeeks_, 24 Mar. 2021. [https://streamgeeks.us/what-computer-do-i-need-to-live-stream/](https://streamgeeks.us/what-computer-do-i-need-to-live-stream/).

[6] N. Uke, R. Thool, "Moving Vehicle Detection for Measuring Traffic Count Using OpenCV," _Journal of Automation and Control Engineering_, Feb. 2012. [http://dx.doi.org/10.12720/joace.1.4.349-352](http://dx.doi.org/10.12720/joace.1.4.349-352).

[7] C. Tonde, "Hardware and Software Platforms for Computer Vision," CS: 534 Computer Vision, Rutgers University, Spring 2022. [https://people.cs.rutgers.edu/~elgammal/classes/cs534/lectures/GPUs.pdf](https://people.cs.rutgers.edu/~elgammal/classes/cs534/lectures/GPUs.pdf).

[8] A. Sharma, V. R. Shrimali, M. Beyeler, “Technical requirements,” _Machine Learning for OpenCV_, 2nd ed., _Packet Publishing Ltd._, Birmingham, UK, Sept. 2019. [https://www.oreilly.com/library/view/machine-learning-for/9781789536300/038d70bd-e186-483b-8ef0-23b344f46ecc.xhtml](https://www.oreilly.com/library/view/machine-learning-for/9781789536300/038d70bd-e186-483b-8ef0-23b344f46ecc.xhtml).

[9] NeuroTechnology, “SentiVeillance SDK,”  _NeuroTechnology_, 2022. [https://www.sentiveillance.com/sentiveillance-sdk/](https://www.sentiveillance.com/sentiveillance-sdk/).

[10] J. Fox, “80 PLUS Bronze vs Gold vs Platinum vs Titanium: Which PSU Rating do you Need?,” _TechGuided.com_, 13 Jun. 2022. [https://techguided.com/80-plus-bronze-vs-gold-vs-platinum-vs-titanium-which-psu-rating-do-you-need/](https://techguided.com/80-plus-bronze-vs-gold-vs-platinum-vs-titanium-which-psu-rating-do-you-need/).

[11] PCPartPicker, “Choose Your Parts,” _PCPartPicker_, 2022. [https://pcpartpicker.com/list/t7gKmr](https://pcpartpicker.com/list/t7gKmr).

[12] “Omni Calculator,” [https://www.omnicalculator.com/other/streaming-bitrate](https://www.omnicalculator.com/other/streaming-bitrate).

[13] Restream Team, “What is a good upload speed for streaming?,” _Restream, Inc._, 1 Jul. 2022, [https://restream.io/blog/what-is-a-good-upload-speed-for-streaming/](https://restream.io/blog/what-is-a-good-upload-speed-for-streaming/).

[14] UserBenchmark, "Compare: Intel Core i5-7300HQ vs. AMD Ryzen 5 3600". [https://cpu.userbenchmark.com/Compare/Intel-Core-i5-7300HQ-vs-AMD-Ryzen-5-3600/m223877vs4040](https://cpu.userbenchmark.com/Compare/Intel-Core-i5-7300HQ-vs-AMD-Ryzen-5-3600/m223877vs4040).

[15] UserBenchmark, "Compare: Nvidia GTX 1650 vs. Nvidia GTX 1050-Ti". [https://gpu.userbenchmark.com/Compare/Nvidia-GTX-1650-vs-Nvidia-GTX-1050-Ti/4039vs3649](https://gpu.userbenchmark.com/Compare/Nvidia-GTX-1650-vs-Nvidia-GTX-1050-Ti/4039vs3649).

## Revisions

12/4/2022 - Downscaled components to cut costs

1/24/2023 - Updated components to factor in YOLO algorithm with CUDA-enabled OpenCV

1/30/2023 - Included compatibility of selected parts

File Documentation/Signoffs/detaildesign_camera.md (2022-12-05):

# Detailed Design for Camera Subsystem within Primary Data Acquisition System

## Function of the Subsystem

The primary data acquisition system will utilize camera sensors to determine the number of cars in the Bell Hall Lot. The cameras will utilize one of two methods for determining the parking count: tracking statically a parking lot sector or tracking dynamically the movement of cars into and out of a sector. These video feeds from these cameras will then be sent to a server where the images will be processed by an artificial intelligence (AI) algorithm to determine the number of cars and thus the number of available Red parking spots in the Bell Hall. This subsystem is a critical subsystem because these cameras will provide the primary data to the system that will determine the count of vehicles in a lot. The cameras is providing this input data to the server.

## Constraints

1. Placement and Performance of Cameras
  * Placing Cameras on Light Posts
    - Figure 1 shows the Red parking spaces in Bell Hall and the light posts scattered throughout the lot. The only approved places that the cameras could be mounted upon are the light posts shown in Figure 1, thanks to Facilities at Tennessee Tech. The light posts, which are 5” square steel and are 25 ft tall on top of a 2 ft cement block. They provide a flat surface for mounting.

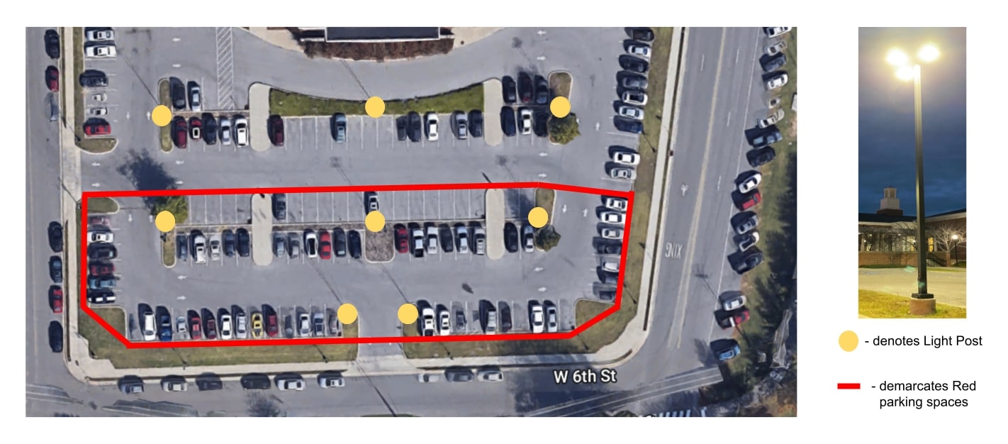
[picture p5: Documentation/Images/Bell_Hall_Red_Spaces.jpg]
Figure 1. Bell Hall Parking Lot with Red Spots and Light Posts

<div align="center"> Figure 1. Red Parking Spots and Light Posts in Bell Hall Lot
<div align="left">

  * Height on Light Posts
    -After consulting with Facilities, the maximum height in which cameras can be installed is 20 ft (22 ft counting the cement block) to avoid the lights shining onto and overheating the cameras at night. To maximize the field of range that the cameras can see, all cameras except Camera 6b will need to be placed at a height of 22 ft.
    - To address the worst-case scenario for the static lots, in which a tall car (e.g. a Toyota Tacoma roughly 7.67 ft) is next to a small car (e.g. a Nissan Sentra roughly 4.74 ft), with the small car in the further spot, to ensure at least 2.69 ft of the parking spot is visible, an angle of incidence from the 2.69 ft point to the camera of 22.7° (derived from the inverse tangent of 2.93 ft, the difference in height of the cars, divided by 7 ft, derived from assuming that the tall car is 1 ft from the parking spot boundary plus 6 ft of the parking spot the small car is in) is required, or a maximum angle that the camera can be pointed of 67.3°. This satisfies all static sectors except Sector 2; however, the frequency this scenario may occur (which is uncommon due to the prevalence of students driving SUVs) as well as that this may provide an error for one parking spot (compared with the acceptable margin of error with the secondary data acquisition system to be roughly 8 parking spots), shows that this risk is acceptable.
    - Due to the presence of a tree that "hugs" the light post adjacent to Sector 6, Camera 6b will need to be placed at an eye level of 5 ft (2 ft cement block plus 3 ft of the post) since this camera is intended for detecting vehicles as they pass by (the same applies to Camera 6a), rather than tracking static parking spots. As shown in Figure 1, this provides enough coverage to see a car coming into or exiting a lot.
    - The worst case scenario is that of in which a Tacoma/tall vehicle is entering Sector 6 near the tree and a Sentra/short vehicle is exiting Sector 6 away from the tree, in which for a time period the tall vehicle will obstruct the short vehicle. However, due to the relative frames, because the vehicle entering the lot is very close to the camera, it will be on the video feed for a much shorter than the the vehicle exiting the lot, so it is highly probable that since a 31° FOV will lead to at least 56 ft of the visible parking spaces visible (and thus the demarcation in which a car can move through that entrance), the worst-case scenario will work itself out as the exiting short car will still be on the feed once the entering tall car is accounted for.
  * Attachment to Light Posts
    - Because drilling into posts is not allowed (as per Facilities), hose clamps will need to be used to mount the cameras. Please refer to Mounting for more information.
  * Casing
    - The casing must protect the cameras from vandalism, weather, birds, etc.
    - The casing also cannot obstruct the view of the lens of the cameras.
    - The casing will be designed by the Mechanical Engineering team. (If not, then the ECE will create the first prototypes of the casing to be later improved by the ME team.)
  * Day vs. Night Performance
    - The cameras are expected to perform properly in daylight, which covers the parking enforcement hours of 7:30 a.m. to 4:30 p.m.

2.  Monitoring of Parking Spaces and Entrances
  * Sectoring of Bell Hall Red Lot
    - Bell Hall has been apportioned into six sectors in a manner to balance the performance of the cameras. The sectors must ensure that if a sector is a statically tracked area (see below) that all parking spots are visible and that if a sector is a dynamically tracked area that entrances can be monitored properly.
  * Statically vs. Dynamically Tracked Parking Sector
    - A "statically tracked" parking sector is an area in which the camera is set to view the parking spots; in other words, the objects of interest are not moving. The objects that the camera is trying to track are non-moving cars in parking spots.
    - For a camera to fully monitor a statically tracked sector, the camera must be able to the entirety of parking spots it is trying to view (thus the field of view must be able to see all of these spots and the resolution must be able to see a car at the furthest point a car can be parked--please consult the top of Figure 3 for these calculations).
    - A "dynamically tracked" parking sector is an area in which the camera is determining if a car is entering or exiting that sector, in which a camera has to be placed at each entrance. The objects of interest are moving and their direction must also be noted (i.e. whether the car is entering or exiting the lot).
    - For a camera to monitor the entrance of a dynamically tracked sector, the camera must be able to the entirety of a car (deemed by the length of a parking spot) in the stretch of driving area right next to the camera light post (thus the field of view must be able to see a whole car this close up and the resolution must be able to see a car at the furthest point a car can drive in that stretch of the parking lot--please consult the bottom of Figure 3 for these calculations).
  * Number of Needed Cameras
    - It has been determined that dividing up the Bell Hall lot into 6 sectors, 5 statically tracked lots and 1 dynamically tracked lot, is the the optimal allocation of cameras to minimize cost while maximizing coverage. Because cameras are not inexpensive, it is imperative that a minimal number of cameras be used but enough to account for all spots, either directly (statically tracked) or indirectly (dynamically tracked). Thus, 7 cameras in total are needed.
    - Whenever it will be summer, the foliage will cover a majority of the light post; thus, the only possible mounting area in which leaves and branches do not obstruct the camera lens is eye-level of 5 ft. In addition, putting a camera on other light posts surrounding Sector 6 will prove too difficult in terms of pixels per foot, angle of camera, and field of view. Thus, Sector 6 has been deemed to be a dynamically tracked parking sector in which cameras will have to be stationed at both ends of the sector to monitor the cars coming in and out of the sector, two cameras total.
    - For the statically tracked sectors, 1 camera will be allocated to each sector, for a total of 5 cameras for these 5 sectors. The sectors were chosen to minimize the minimum field of view and resolution needed for the cameras. The analysis shown in Figure 3 shows more of the validation of the sectors.

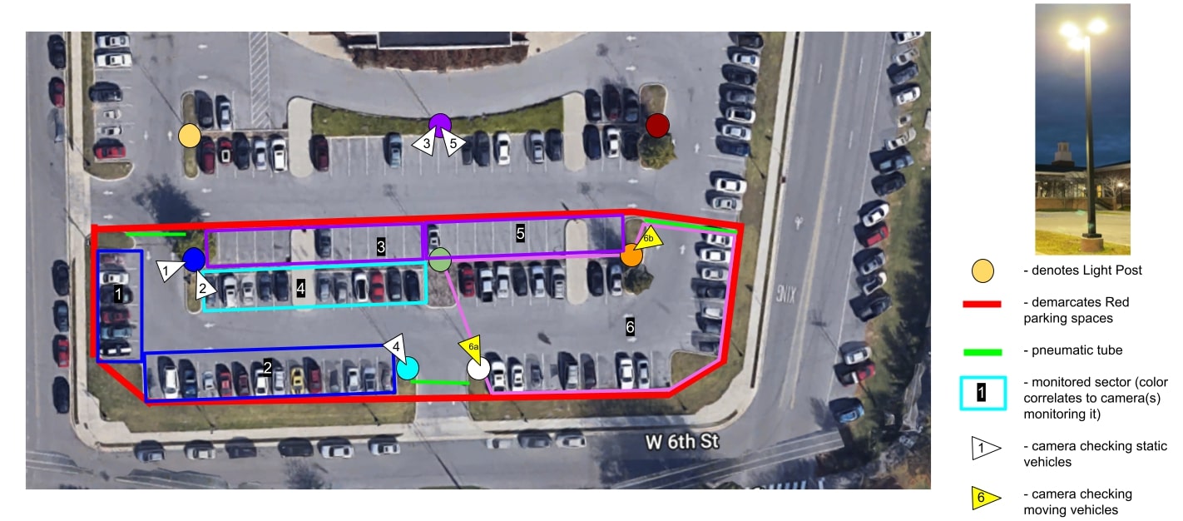
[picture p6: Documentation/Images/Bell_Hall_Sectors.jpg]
Figure 2. Bell Hall Parking Lot Sectors

<div align="center"> Figure 2. Bell Hall Red Zone Divided Up into Sectors
<div align="left">

3. Mounting
  * The mounting will be taken care of by a separate subsystem. This will include a mount to the pole as well as the mount to the cameras. The selected mounting must be able to handle the weight of the cameras and whatever is powering the cameras.

4. Maintainability
  * These cameras will require minimum maintenance once installed, and there should be a way to “recalibrate” the cameras remotely without having to physically access the cameras.

5. Minimum Field of View, Resolution, and Frame Rate
  * Minimum Field of View
    - The cameras need to be able to have a field of view that could view all parking spots in Sector 1 through 5, as well as see a moving car right near the cameras at the entrances of Sector 6. The measurements used for the length and width of a car/parking spot are the measurements of a parking spot in Bell Hall, which were determined to be to be 18.87 ft x 8.69 ft (575 cm x 265 cm). The measurements of the minimum field of view needed for each sector (static sectors 1 to 5 and dynamic sector 6, with entrance cameras denoted as 6a and 6b) can be seen in Figure 3 below. Overall, a field of view of 98° is needed for this system.
    - For static Sectors 1 through 5, an overall minimum field of view of 96° is needed. The field of view was determined by finding the angle needed to see all of that sector's parking spots in entirety. In order, a field of view of 77°, 96°, 61°, 91°, and 75° are needed to see all of the parking spots in Sectors 1, 2, 3, 4, and 5, respectively. Thus, an FOV of 96° is needed to view all of the spots in the static parking lots. We believe that a minimum field of 96° is a reasonable needed FOV that balances the number of cameras (which are not inexpensive) and their performance. Please consult the constraints on Positioning of Cameras and Figure 2 for more on the sectoring of the Red zone of Bell Hall lot.
    - For dynamic Sector 6, an overall minimum field of view of 98° is needed because this is the FOV that is able to see the full length of a car (18.87 ft, the length of a parking spot in Bell Hall) close-up to the camera. For Entrance A, the camera must be able to see the full length of a vehicle 10 ft away from the camera, and for Entrance B, the camera must be able to see the full length of a vehicle 22 ft away from the camera. This length can be seen with an FOV of 98°, though their heights will differ (22 ft for A and 5 ft for B due to the tree at Entrance B).
  * Minimum Resolution
    - To determine a minimum resolution of the cameras, it was necessary to research other computer vision efforts to identify vehicles and the resolution in which the training and testing images were. The computer vision algorithms implemented in [1] and [2] which detect and/or identify vehicles used training set images of the rear side of cars that were 64 x 64 pixels. A standard car is on average 5.8 feet [3], which translates to roughly a little over 10 pixels per foot (or 100 pixels per square foot) for these images of cars to be identified as such. Thus, the cameras must have a minimum pixels per foot of 10 pixels per foot (or 100 pixels per/square foot) at the furthest spot in which a car can be seen from the camera to identify the presence of a car in a parking spot since these AI algorithms are able to identify/detect vehicles at this pixel per foot. It is understood that a camera will not concentrate all of its pixels onto the needed area (i.e. cars), which is why the 10 pixels per foot applies to the furthest point in which a car can be seen, and this "line" must span the minimum field of view required for that sector.
    - Pixels per foot can be calculated by dividing the number of horizontal pixels (the first number in a resolution, i.e. the H in (H) x (V)) by the distance. Figure 1 shows the minimum pixels per foot calculations performed on a 1080p camera, which has a resolution of 1920 x 1080. As seen in Figure 1, a 1080p provides at least 10 pixels per foot for cars in all statically and dynamically tracked sectors (1 through 6). However, a 2 MP camera, which is slightly lower resolution at 1600 x 1200 [4], also provides a sufficient the sufficient 10 pixels per foot.
    - This 10 pixels per foot minimum resolution applies to both the statically tracked and dynamically tracked sectors. For the statically tracked sectors, the 10 pixels per foot must apply at the line in which a car can be furthest parked/seen in the camera vision. For the dynamically tracked sectors, the cameras must be able to view a car driving at the furthest point it could move at that entrance (not in parking spots) at 10 pixels per foot. Please consult the below Figure 3 for the measurements for all cameras for statically tracked Sectors 1-5 and the entrances for dynamically tracked Sector 6.

6. Data Obtainability and Minimum Image Acquisition Rate
  * Data Obtainability
    - A live video feed, or at minimum a series of images, must be able to be obtained from the cameras and be able to be sent wirelessly to the server for image processing. Thus, the camera must support a protocol or standard (i.e. ONVIF, RTSP) that allows for us to obtain video streaming and be able to communicate the cameras with an external server.
    - ONVIF is a standardized method to communicate to IP surveillance cameras with servers, etc. [5]. RTSP is a protocol that allows for video and audio streaming over a network [5]. The camera should be able to support ONVIF, RTSP, or both.
    - The wireless communication from the cameras to the server and vice versa will be addressed in a later subsystem, though the camera must have some means of being connected to a wireless transmission system or have it embedded. The cameras must be able to support streaming protocols.
  * Minimum Image Acquisition Rate
    - The minimum image acquisition rate is determined by the need for an adequate frame rate to capture moving cars through the entrances of the dynamically tracked Sector 6, and in particular Camera 6b in which a car can be visible in a 19.2 ft field of view that is 22.4 ft away from the camera.
    - The cameras for the statically tracked lots monitor and take images of static parking spots, and they will take images that determine if the spot is filled by a car or not. Thus, the minimum frame rate will be based off the dynamically tracked lots.
    - The speed limit in the Bell Hall Parking lot is 15 mph, though it is expected that some students will drive higher at 25 mph through these entrances. Thus, a car entering Entrance B of Sector 6 will be in the field of view of the camera for ( (19.2 ft / 5280 ft/mi) / 25 mi/h * 60 m/h * 60 s/m ) = 0.524 s, or 524 ms. To ensure that a car entering Entrance B at this speed is recorded in images by Camera 6b, a frame rate of 5 fps is needed to capture at least 2 or 3 images of the car for the AI to determine its presence and its direction. However, the lowest frame rate that a camera can support is 24 fps [7], which means that a 24 fps camera at minimum is required since this image rate will provide at least 20 images of a car going through the entrances to the AI application.

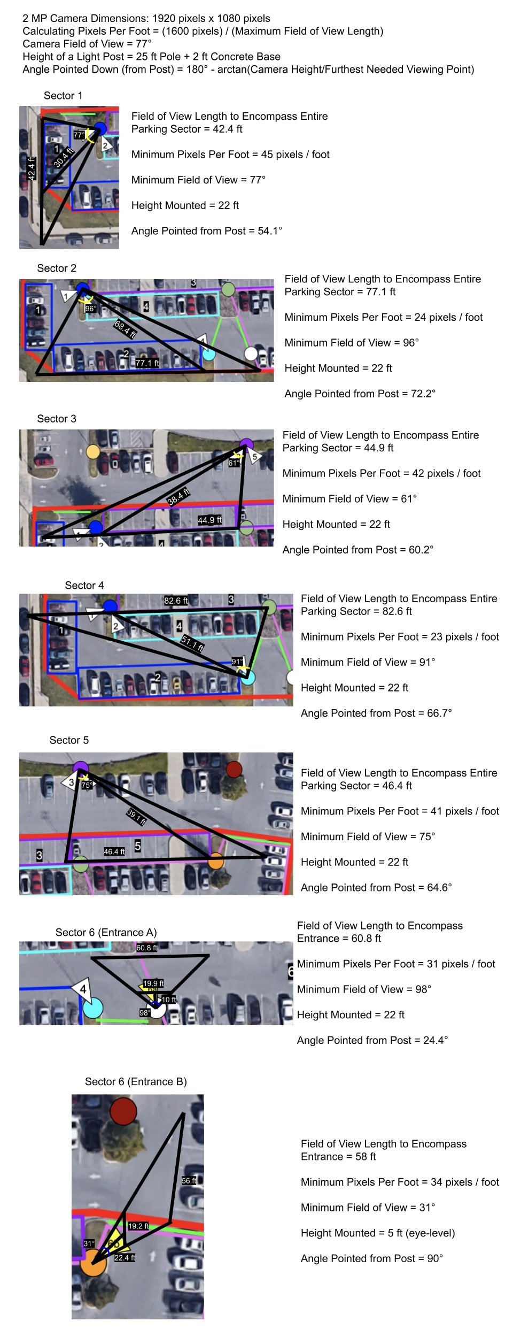
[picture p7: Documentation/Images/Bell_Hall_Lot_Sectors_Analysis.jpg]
Figure 3. Bell Hall Sectors Analysis

<div align="center"> Figure 3. Minimum FOV and Resolution Requirements for Each Sector in the Bell Hall Red Zone
<div align="left">

## Buildable Schematic

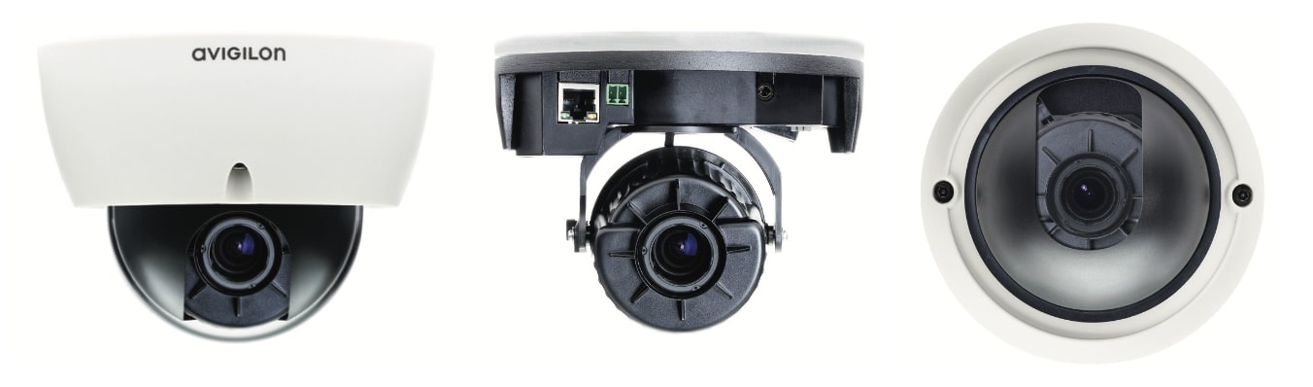
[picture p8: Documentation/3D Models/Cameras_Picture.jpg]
Figure 4. Avigilon Cameras

<div align="center"> Figure 4. Selected Avigilon Dome Cameras

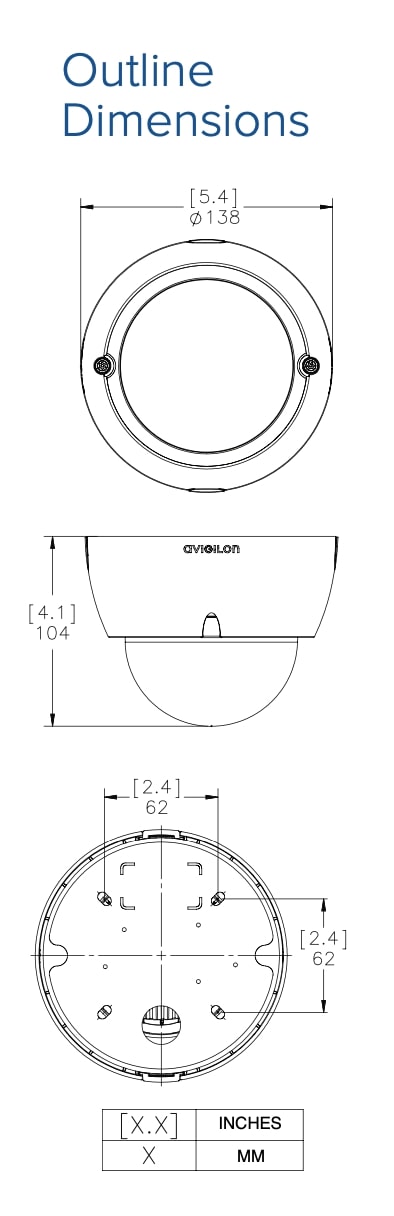
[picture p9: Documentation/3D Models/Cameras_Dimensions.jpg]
Figure 5. Avigilon Cameras

<div align="center"> Figure 5. Dimensions of Avigilon Dome Camera

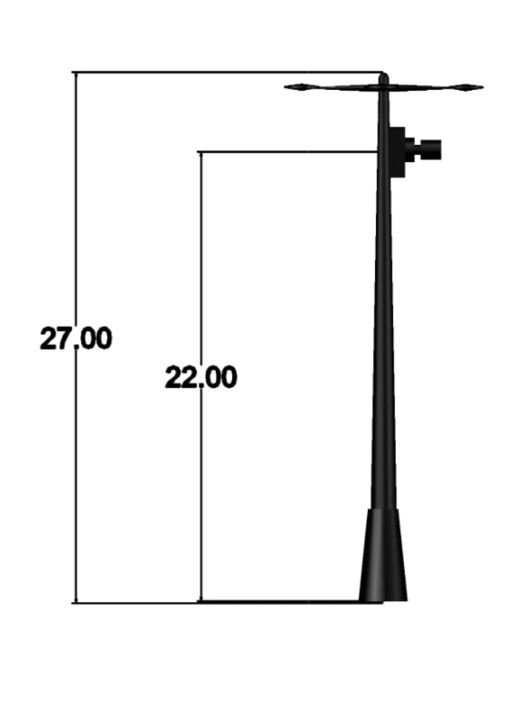
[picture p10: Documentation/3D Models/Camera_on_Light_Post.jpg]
Figure 6. Mounting of Cameras on Light Posts

<div align="center"> Figure 6. Mounting of Cameras on Light Posts
<div align="left">

## Analysis

1. Selected Camera
  * Camera to Be Used: Avigilon 2.0 Megapixel Day/Night H.264 HD Indoor Dome Camera [6]

2. Meeting Minimum Field of View and Resolution
  * The Avigilon Indoor Dome Camera has a field of view of 98°, which matches our minimum FOV needed to see all cars in the static sectors 1-5 as well as a car close-up to the cameras at the entrances of Sectors 6.
  * The cameras also have a resolution of 2 MP and an active pixels of 1920 x 1080, which satisfies the minimum resolution needed to provide 10 pixels per foot for all cars that can be seen by the cameras.

3. Day vs. Night Performance
  * Because these cameras are indoor cameras, they are meant to be used with light, thus meaning they can see during the day.

4. Attainability
  * An important note is that these cameras can be obtained from the Information Technology Services (ITS) for no charge, and ITS is willing to provide us the number of cameras needed (7). Thus, even though the sectoring of the parking lots were created to minimize the cost of cameras, still we can obtain the number of cameras to cover the entire Bell Hall Lot.

5. Mounting and Casing
  * The dimensions of the camera is 138 mm x 104 mm (5.4” x 4.1) with a weight of 0.53 kg (1.17 lbs). Thus, it is highly reasonable to expect that these cameras are light enough to be mounted and small enough to create a suitable casing.

6. Data Obtainability and Image Acquisition Rate
  * The Avigilon cameras are ONVIF compliant as well as have the RTSP protocol, so we can communicate with the cameras to obtain video/image feed.
  * The cameras also support streaming protocols such as RTP/UDP and RTP/RTSP/HTTP/TCP for data transmission over networks.
  * The cameras have an image rate (frame rate) of 30 fps, which is above the minimum rate of image acquisition.

## Bill of Materials

| Name of Item | Description | Used in which subsystem(s) | Part Number | Manufacturer | Quantity | Unit Price | Total |
| --- | --- | --- | --- | --- | --- | --- | ----- |
| Avigilon 2.0 Megapixel Day/Night H.264 HD Indoor Dome Camera | Camera | Primary Data Acquisition | 2.0-H3-D1 | Avigilon | 7 | $0.00 | $0.00 |
| | | | | | | | **$0.00** |

  * Note: ITS will be supplying these cameras, hence the cost of $0.00.

## Cited Sources

[1] A. Gunzi, “Vehicle Detection and Tracking using Computer Vision,” _Chatbots Life_, 7 Mar 2017. [https://chatbotslife.com/vehicle-detection-and-tracking-using-computer-vision-baea4df65906](https://chatbotslife.com/vehicle-detection-and-tracking-using-computer-vision-baea4df65906).

[2] B. Djukic, “Detecting vehicles using machine learning and computer vision,” _Towards Data Science_, 25 Apr 2017. [https://towardsdatascience.com/detecting-vehicles-using-machine-learning-and-computer-vision-e319ee149e10](https://towardsdatascience.com/detecting-vehicles-using-machine-learning-and-computer-vision-e319ee149e10).

[3] S. Meyer, “STUDY: Average Car Size is Increasing – will roads still be safe for small cars and pedestrians?,” _The Zebra_, 2022. [https://www.thezebra.com/resources/driving/average-car-size/](https://www.thezebra.com/resources/driving/average-car-size/).

[4] "A Practical Guide to CCTV Video Resolutions," _Optiview_, 2022. [https://optiviewusa.com/cctv-video-resolutions/](https://optiviewusa.com/cctv-video-resolutions/).

[5] A. Hurley, "ONVIF vs. RTSP: Which is better?," _VXG_, 6 Oct. 2022. [https://www.videoexpertsgroup.com/onvif-vs-rtsp/](https://www.videoexpertsgroup.com/onvif-vs-rtsp/).

[6] "2.0 Megapixel Day/Night H.264 HD Indoor Dome Camera," _Avigilon_, 2013. [https://www.securityinformed.com/datasheets/avigilon-2-0-h3-d1-ip-dome-camera/co-3126-ga/2.0-H3-DdatasheetEN2.pdf](https://www.securityinformed.com/datasheets/avigilon-2-0-h3-d1-ip-dome-camera/co-3126-ga/2.0-H3-DdatasheetEN2.pdf).

[7] "Frame Rate - Everything You Need to Know," _Nashville Film Institute_. [https://www.nfi.edu/frame-rate/](https://www.nfi.edu/frame-rate/).

# Revisions

11/15/2022 - Addressed previous comments by adding CAD schematics of cameras, more in-depth analysis of required field-of-view, re-scoping of this detailed design to just camera selection

11/19/2022 - Re-arranged information so that specifications section actually have specifications and analysis verifies that the cameras meet those specifications

11/20/2022 - Fixed broken links in markdown file

11/29/2022 - Reformatted signoff so that constraints are adequately mentioned with new information.  Analysis only shows how the cameras meet the specifications.

11/30/2022 - Added more discussion on data transmission/obtainability and dynamically tracked parking spot constraints.

12/1/2022 - Removed extraneous descriptions in constraints and added minimum frame rate constraints.

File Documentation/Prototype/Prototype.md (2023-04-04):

# Prototype

## Original Requirements

All of the below requirements demonstrate minimum functionality of every subsystem. These requirements compose the original agreement for the prototype design.

### Primary Data Acquisition System

One Static Tracking Camera
 - Connected to Linux server or other PC/laptop via Ethernet.
 - Must be able to obtain footage from the camera and upload images to the server.
 - Must be powered via solar power.

### Server

Server
 - Must be able to view a video via Ethernet from a camera.
 - Must be able to communicate with the remote database for the mobile application and the sign, i.e. send a number from the server which is shown on the mobile application and the sign.

### Sign

Sign
 - Must be able to display a number that is sent by the remote server.
 - Must be powered via solar power.
 - Must be able to communicate with server wirelessly using the wireless communication module, i.e. receive a number from the server and display it.

### Mobile Application

Mobile Application
 - Shows (arbitrary) data that is sent from the server.
 - Note: the mobile application is under the computer science team, so their work will be integrated with ours.

## Substitutions

Since we were not able to design a fully functional power system, and since the wireless communications devices have not arrived, we propose to substitute power and wireless communication for increased functionality in the cameras and AI processing.

### Primary Data Acquisition System

Rather than just one camera, we propose implementing two cameras (the number of cameras agreed upon for our final deliverable) for our prototype to make up for the lack of power and communications.

Two Cameras
 - One static tracking camera
    - Must be able to obtain video feed of stationary cars in a parking lot from camera via Ethernet.
    - The goal of this camera is to obtain frames of cars in stationary parking spots.
 - One dynamic tracking camera
    - Must be able to obtain video feed of moving cars in a parking lot from camera via Ethernet.
    - The goal of this camera is to obtain frames of cars moving across a parking lot.
 - One camera is to be demonstrated at a time when connected via Ethernet to the Linux server.
    - The Linux server has only one Ethernet port, which is already taken up by an Ethernet cable connected to the Tech network. It also has only one available USB port, in which a USB-to-Ethernet adapter can be plugged in. Therefore, only one camera can be connected to the server via Ethernet at a time.
    - Cameras will NOT be powered by solar power. Instead, they will be powered via the the block terminal.
 - The cameras will be placed next to a window in the Capstone Lab to look down upon the Gold parking lot in the Engineering Quad. The Engineering Quad will serve as our prototype test lot to show basic functionality.

### Server

AI was not in the original prototype design, so we propose substituting power and wireless communications for two working vehicle detection models, one for static tracking and another for dynamic tracking.

Two Vehicle Detection Models
 - Static tracking model
   - Performs pre-processing of frames to black out part of the frame so that the algorithm only performs on a selected region.
   - Algorithm is performed to detect the number of vehicles in the selected portion of the lot. This number is then sent to the remote database that also interfaces with the mobile application.
 - Dynamic tracking model
   - Adds two lines to each frame that is chosen to be processed and determines the direction that a vehicle is going based on which line it runs in first.
   - The data on the remote database will be updated based on the traffic flow in and out of that area.
 - Both models must be able to perform frame skipping that will process every Nth frame and keeps up with the rate in which frames are received. In other words, frame-skipping does not affect the outputs being real-time.

### Mobile Application

We also propose substituting power and wireless communications for functionality in which the number of available parking spots can be determined from the two models and sent to the mobile application and sign.

Remote Database
 - The remote database will perform the calculations to determine the number of available spots from both the static tracking model and the dynamic tracking model.

### Sign

Sign
 - Will display data pulled directly from the remote database, i.e. the current number of available parking spots entered on the remote database for the mobile application.
 - Will be powered by a computer, which will also serve as the communication system to allow the sign to communicate to the remote server via Wi-Fi.

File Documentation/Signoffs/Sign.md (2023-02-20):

# Sign System Detail Design

## Function of the Subsystem

The sign will be a physical entity at the entrance of the parking lot that will display the current number of available parking spots in the parking lot. This will allow students to decide if they even enter the parking lot and has the potential to save the students time searching for a parking spot. This subsystem is to be used in unity with the mobile application which will also display the same information. It will acquire its data from the server/database wirelessly with the initial data being from the data acquisition subsystem(s). It will then use custom seven-segment displays, a microprocessor, and a power transistor circuit to display this information on the physical sign.

## Constraints

1. Seven-Segment Display & Controls
- Must have waterproof controllable display directly viewable in the daylight ("the minimum luminance required for a LED to be visible in direct sunlight is around 10,000 to 15,000 millicandela (mcd). However, this can vary depending on the specific application and viewing conditions. For example, a LED used in a traffic signal or sign may require a higher luminance level to ensure visibility in a busy urban environment with high levels of background light." [12]) and from the road capable of showing number of open parking spots 
- Must have a microcontroller with at least a 14 Digital output PINs, RX/TX PINs, and capable of connecting a external wireless communication module to connect to the 
- Must have a power circuit rated for switching display LEDs on/off using microcontroller output PIN voltage and power from separate subsystem

2. Outdoor Physical Sign/Stand
- Must be large enough to hold controllable display and static text viewable from the road (at least 3 inches in height [5])
- Must be able to withstand reasonable weather requirements (storm, mid to heavy wind, etc.)

3. Weatherproofing
- Must protect Seven-Segment display controls from dust and water (Note: This design will be handled by the sign power subsystem)

## Buildable Schematic

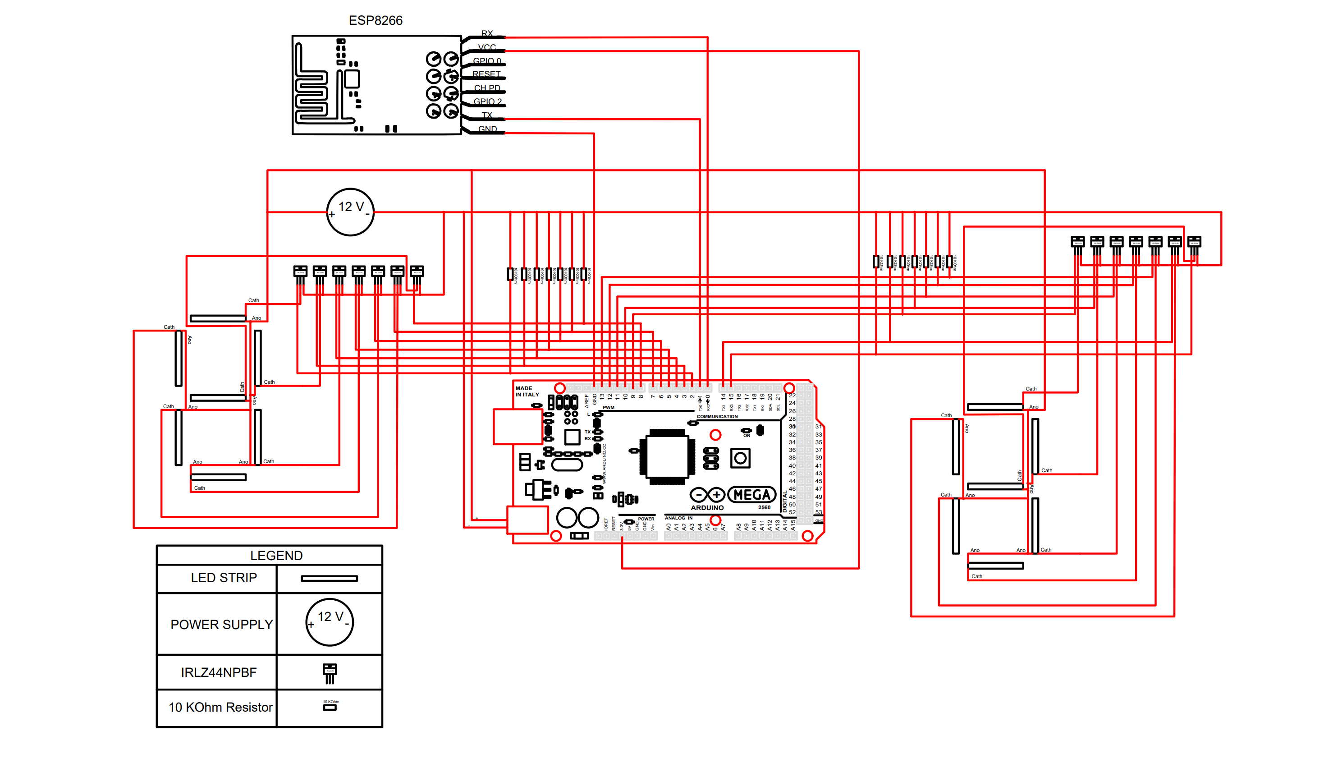
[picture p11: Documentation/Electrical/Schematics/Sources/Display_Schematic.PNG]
Figure 1. Arduino Circuit Diagram

<div align="center"> Figure 1. Arduino Circuit Diagram
<br />
<div align="left">

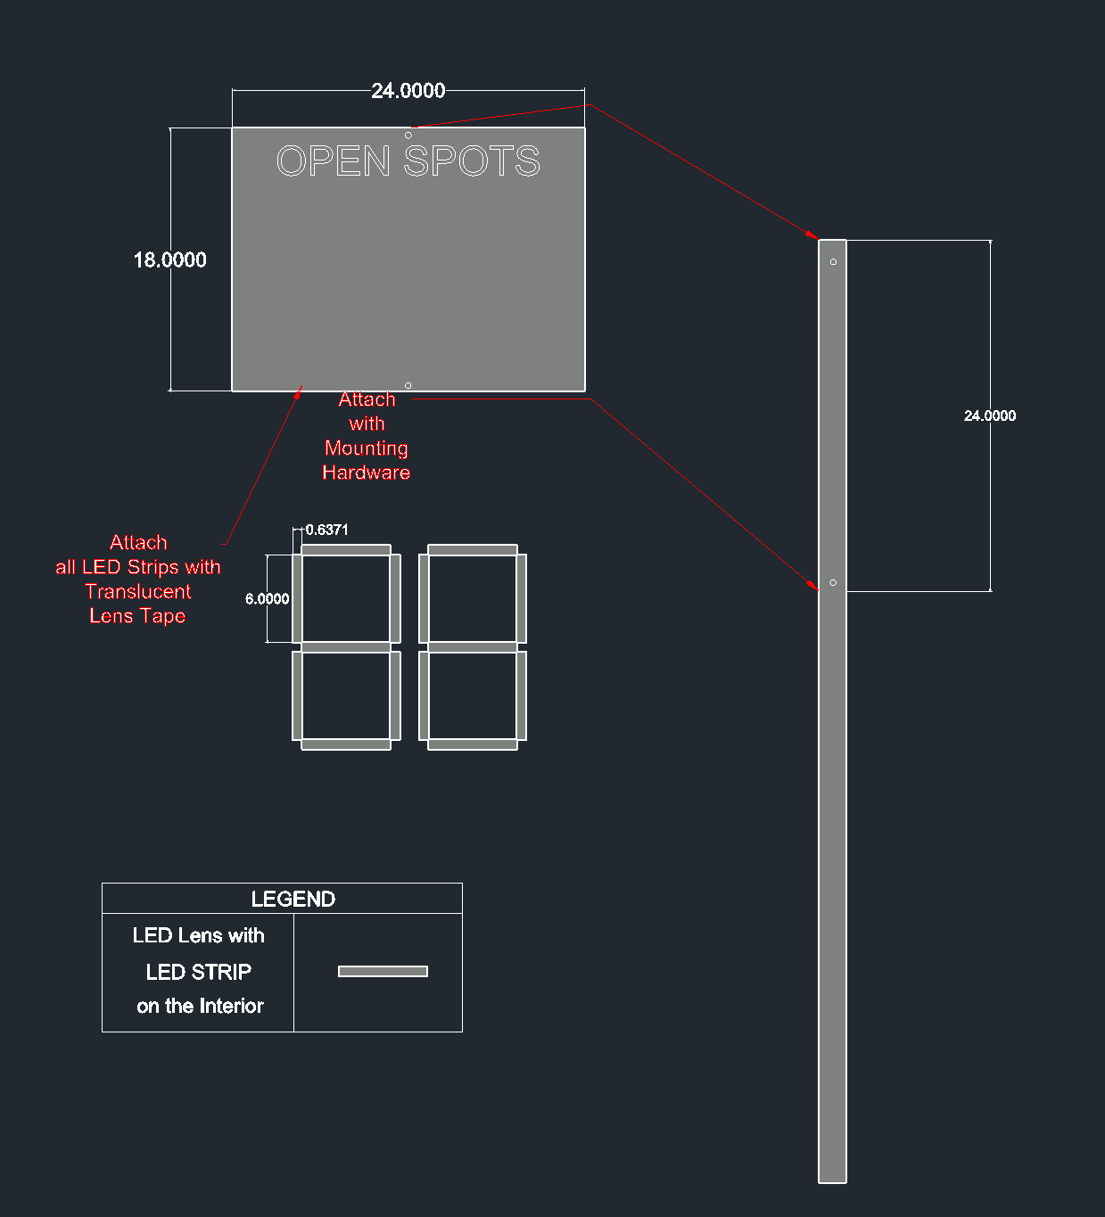
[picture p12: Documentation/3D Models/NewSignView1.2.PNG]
Figure 2. Physical Sign Schematic

<div align="center"> Figure 2. Physical Sign PDF Schematic 
<br />
<div align="left">

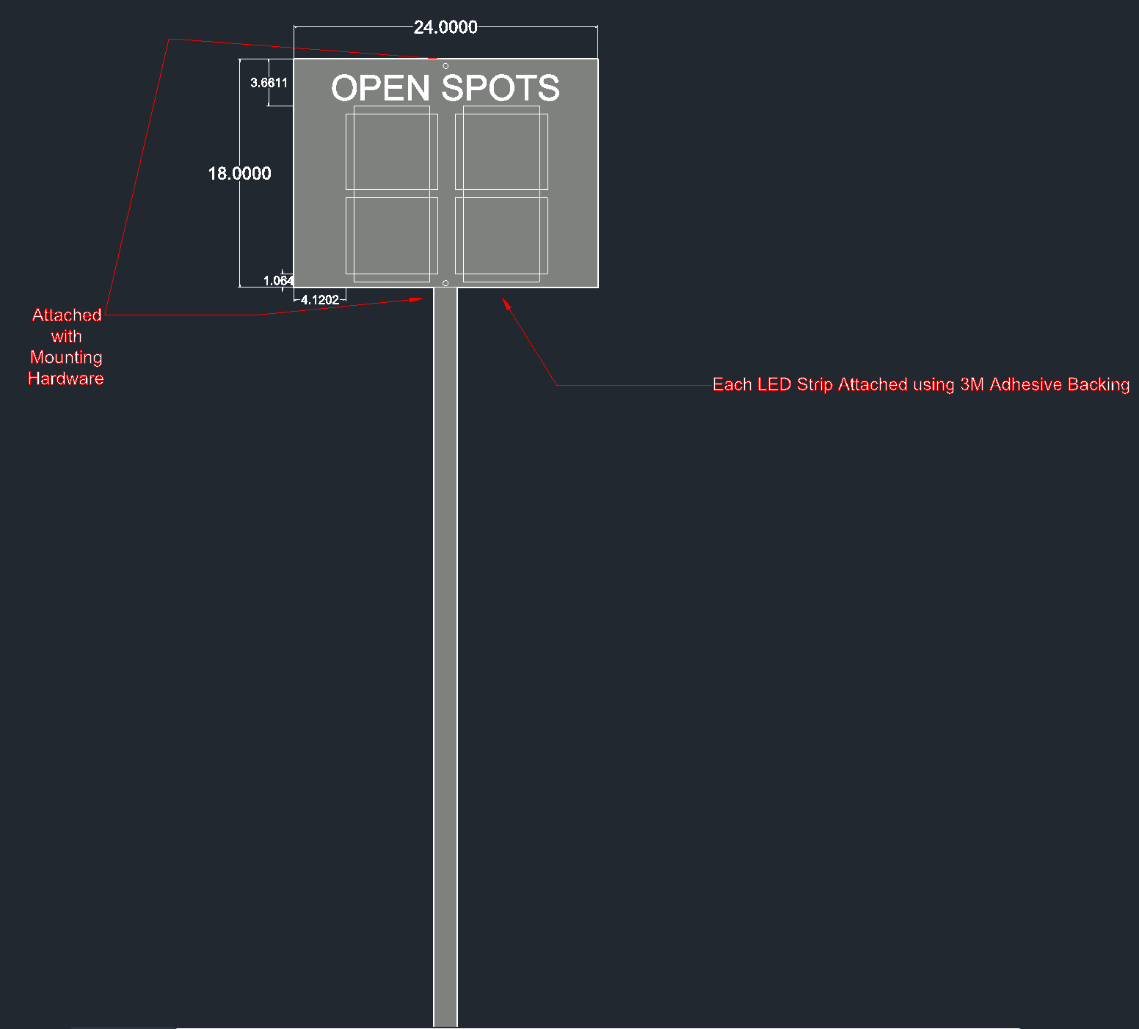
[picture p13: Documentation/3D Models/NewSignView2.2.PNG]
Figure 3. Physical Sign Schematic View 2

<div align="center"> Figure 3. Physical Sign Final Product Schematic View
<br />
<div align="left">

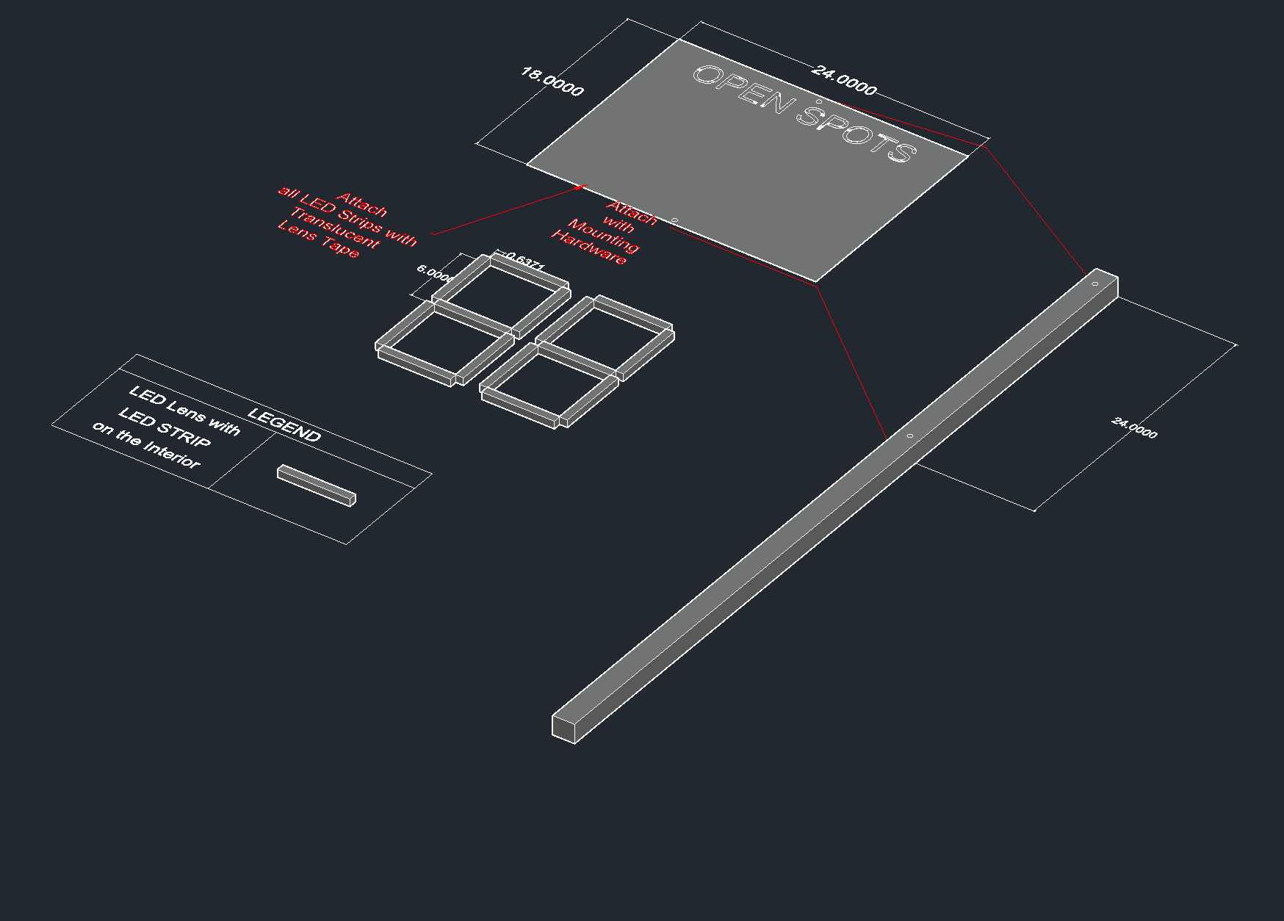
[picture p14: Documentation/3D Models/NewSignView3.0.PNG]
Figure 4. Physical Sign Schematic View 3

<div align="center"> Figure 4. Physical Sign 3D Schematic View
<br />
<div align="left">

Note: 
- The dimensions on the final view show the placement of each LED strip/Lens. 
- Each LED strip's wires will also be sent to the weatherproof box holding all circuit components (In the Power subsystem signoff). The necessary holes will be drilled through the sign behind each Lens/Strip for each wire to be fed through. 	

## Analysis

1. Seven-Segment Display & Controls

a. LED Strips 

- Will consist of 7 red 12 V LED light strips per display (14 total)
- Wires will be fed through the sign through drilled holes at the end of each strip
> - Each LED strip is roughly 6 inches long
> - Each segment is roughly 7 inches (W) x 13 inches (H) 
> - The following analysis shows how these seven-segments will meet the required constraints of visibility:
> > - Length of road parallel to main entrance is roughly 100 feet and width is roughly 20 feet [6]
> > - Maximum viewing distance when entering the lot is 102 feet [6]
> > - Optimum viewing distance is 120 feet and maximum viewing distance is 525 feet [5]

- Keiurot LED strips chosen for:
> - Already waterproof (IP67 rated)
> - LED strips rated for 1000 Lumens each (18 LEDs total per strip so 55.5 Lumens per LED) , a max viewing apex angle of 160 degrees (average max for LED strips) equates to roughly 10,680 millicandela. which meets the constraint of at least 10,000 millicandela total for daylight visibility. 
> - 3M adhesive weather-resistant backing to attach directly to the sign.
> - Cuttable to size of 6 inches per strip to meet the size constraint of creating a viewable display from the road (7 inch x 13 inch seven-segment displays)
The specs/features above show that the product meets the required constraints.

- Gaffer Power Transparent tape chosen for:
> - A lensing to cover the Keiurot LED strips to meet the constraint of visibility due to the necessity of not staring directly at the LEDs. 
> - This tape can meet all size constraints of the Keiurot LED strips due to it being cuttable to the preferred size and can also be layered in necessary while maintaining a clean finish.
> - The tape is weather resistant for long-term durability. 
>-  The tape is also patterned which allows for the light to be dispersed along the tape lens.
> - Note: This cover allows the LED strips to directly be viewed by shining onto a translucent surface. 

b. Microcontroller

- Arduino Mega board chosen for:
> - Necessary capabilities for number of PINs, serial communication, and output for ESP8266 module
> - 54 digital I/O ports and multiple serial communication PIN options
> - 3.3 V output for ESP8266 module and 16 PINs for outputs to power transistors and serial communication to external module
> - Arduino's IDE works well with ESP8266 module 

The specs/features above show that the product meets the required constraints.
	
c. Power Transistor Circuits

- Power transistor circuit used for each LED, consisting of IRLZ44N power transistor, 12V DC source, 10 KOhm resistor, and grounding
- Each transistor connected to an Arduino Mega digital I/O pin

- IRLZ44NPBF power transistors chosen for:
> - Rated for up to 55 V and 47 A (VDSS) which meets the required constraints of 12 V and 0.7 A per LED strip
> - VGS(th) is 1 V which meets the required constraint of 5V output from Arduino I/O PINs

Note: Each transistor will be switched on and off by the Arduino effectively opening and closing the circuit with 12 V constantly being supplied to each LED strip as seen in Figure 1.

The specs/features above show that the product meets the required constraints.

2. Wireless Data Transfer Module

- The Sparkfun ESP8266 Module was chosen for:
> - Its wireless capabilities
> - The module is very compatible with the Arduino Mega board and its IDE
- In-depth analysis can be found in the corresponding communication signoff.

The specs/features above show that the product meets the required constraints.
	
3. Outdoor Physical Sign/Stand

- The RoadTrafficSigns Custom 18” x 24” Aluminum Sign was chosen due to it meeting the size constraint of being to at least be able to hold both seven segment displays totalling 16 inches x 13 inches (each display being 7 inches x 13 inches with 2 inches of spacing).

- This sign also has customizable text options (roughly 3.6 inches in height with a max readable distance being roughly 130 feet away [5]) for placement and size when ordering that meets the static text constraint.

- This will then be mounted to the post shown in the power subsystem design using the add-on mounting hardware with the custom sign. 
 
4. Power 

The power that will be sent to the sign will be a separate subsystem sending out 12 Volts and the required current output for connected components. This will be sent to each LED strip on the sign and to the Arduino. 

The in depth analysis of this and the solar panel mounting to the post will be in the corresponding power signoff. 
Note: The detailed schematic and design for the post will be in the power detail design.

5. Weatherproofing

Weatherproofing will be designed in the Sign Power subsystem. 
Note: This will include the housing for all of the transistors, Arduino, communication module, and battery.

## BOM for Sign

| Name of Item | Description | Used in which subsystem(s) | Part Number | Manufacturer | Quantity | Price | Total |
| --- | --- | --- | --- | --- | --- | --- | ----- |
|Arduino Mega 2560 REV3 [A000067]| "Microprocessor, 54 digital I/O pins, 16 analog inputs "| Sign| 2560 R3| Arduino| 1| $48.40| $48.40|
|Keiurot Car Led Strip Lights| "2CM Waterproof Led Light Strips for Cars Motorcycles Golf Cart Interior & Exterior Marine Boat Red Led Strip 12V 5050 18SMD Pack of 4"| Sign| 4P-MDLEST0011-R| Keiurot| 4| $12.69| $50.76|
|IRLZ44NPBF| "N-Channel 55 V 47A (Tc) 3.8W (Ta) 110W (Tc) Through Hole TO-220AB"| Sign| IRLZ44NPBF| Infineon Technologies| 14| $1.52| $21.28|
|WiFi Module - ESP8266 (4MB Flash)| Self contained SOC with integrated TCP/IP protocol stack that can give any microcontroller access to your WiFi network| Sign| WRL-17146| Sparkfun| 1| $7.50| $7.50|
|Custom 18” x 24” Aluminum Sign| Custom Aluminum Sign with Custom Wording| Sign| K-3428-BK| RoadTrafficSigns| 1| $37.75| $37.75|
|Post Attachment Kit| 2 Bolts for Heavy Duty Posts and 2 Bolts for Economy Posts Attachment Hardware for Posts - 4 bolts| Sign|	K-KIT2| RoadTrafficSigns| 1| $1.87| $1.87|
|Transparent Duct Tape| Ultra High Performance Weather Resistant Tape for Discreet| Sign| GP-ClrDctPrnt| Gaffer Power| 1| $12.88| $12.88|
|Total| | | | Total Components| 24| Total Cost| $180.44|

## Revisions

Rev. 1 
- Added more detail to 3D schematic
- Updated Analysis and Constraints with more detail
- Switched some info in Analysis to Constraints

Rev. 2
- Clarified LED strip and vinyl poster mounting in correlation to the 3D buildable schematic.
- Removed unnecessary text from Constraints section.
- Added mounting tape to BOM.

Rev. 3
- Reorganized info completely/cut out most paragraphs and listed spec/constraints.

Rev. 4
- Added info about LED visibility in daylight.

Rev. 5
- Changed design from A-Frame sign to post with aluminum sign and clarified details about this in the analysis, BOM, and sources. 

Rev. 6
- Redefined LED light analysis
- Fix Citations
- Clarified transistor analysis and constraints

Rev. 7
- Clarified LED visibility (size and brightness)

Rev. 8
- Added Lens cover for LED strips

Rev. 9
- Changed info on LED brightness and updated 3D schematic

Rev. 10
- Added more PDF schematic stages/steps and views to make it buildable.
Rev. 11
- Adjusted custom sign letter print size and changed lens housing to a transparent tape lens due to size restrictions
-Adjusted schematic

## Cited Sources
 [1] “Arduino Mega 2560 REV3 [A000067],”amazon.com, 2022.
https://www.amazon.com/ARDUINO-MEGA-2560-REV3-A000067/dp/B0046AMGW0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

[2] “Car Led Strip Lights 32CM Waterproof Led Light Strips for Cars Motorcycles Golf Cart Interior & Exterior Marine Boat Red Led Strip 12V 5050 18SMD,Pack of 4,” amazon.com, 2022. https://www.amazon.com/Lights-Waterproof-Motorcycles-Interior-Exterior/dp/B09NBFTN34?th=1

[3] “IRLZ44NPBF,” digikey.com, 2022.
https://www.digikey.com/en/products/detail/infineon-technologies/IRLZ44NPBF/811808

[4] “WiFi Module - ESP8266 (4MB Flash).” sparkfun.com, 2022.
https://www.sparkfun.com/products/17146

[5] “Sign Letter Height Visibility Chart.” Signazon.com, 2022. https://www.signazon.com/help-center/sign-letter-height-visibility-chart.aspx

[6] “Detailed Design for Camera Subsystem within Primary Data Acquisition System”. Github.com, 2022. https://github.com/kesternucum/ECE-Capstone-Team3/blob/main/Documentation/Signoffs/detaildesign_camera.md

[7] "Flemoon Large Outdoor Electrical Box (12.5 x 8.5 x 5 inch), IP54 Waterproof Outdoor Extension Cord Cover Weatherproof, Protect Outlet, Plug, Socket, Timer, Power Strip, Holiday Light Decoration, Black." Amazon.com, 2022. https://www.amazon.com/Flemoon-Electrical-Waterproof-Weatherproof-Decoration/dp/B09NLW5HMX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

[8] “Nits vs Lumens vs Luminance.” New Haven Display, 2022. https://newhavendisplay.com/blog/nits-vs-lumens-vs-luminance/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,by%203.426.%20How%20to%20convert%20lumens%20to%20nits%3F

[9] “18" x 24" Customizable Horizontal Black Sign Template.” RoadTrafficSigns, 2022.
https://www.roadtrafficsigns.com/fos/custom-metal-sign/custom-metal-sign-18x24/sku-k-3428-bk

[10] “Candela.” Nist, 2022.
https://www.nist.gov/si-redefinition/candela

[11] Illuminating Engineering Society (IES) Lighting Handbook, 10th Edition, Chapter 27: Daylighting Metrics, Section 27.2.2 "Luminance Contrast Ratio", and Section 27.3.3 "Minimum Luminance".

[12] “Transparent Duct Tape, Ultra High Performance Weather Resistant Tape for Discreet, No Show Repairs and Mounting | Residential, Commercial and Industrial Uses | by Gaffer Power (2 Inch x 20 Yards).” amazon.com, 2022. https://www.amazon.com/Transparent-Performance-Residential-Gaffer-Power/dp/B076J2BS1B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

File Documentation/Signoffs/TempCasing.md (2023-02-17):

# Primary Data Acquisition Temporary Casing Detail Design

## Function of the Subsystem
The temporary casing for the cameras will be a minimal design meant to protect the cameras from precipitation. This is due to them only being rated for indoor use.
 
## Constraints
- Must fit one camera per casing (5.1 in x 5.1 in x 4.1 in)
- Must be able to protect cameras from precipitation/waterproof until permanent casing is complete
- Must at least have clear acrylic front and bottom sides to casing
- Must be durable enough to drill/cut through (non-brittle plastic) for mounting of camera to case and for the hose clamp to the case 
- Must have two hose clamps at least 22 inches in length each for each casing (20 inch pole perimeter) 

## Buildable Schematic
Note: All units are in Inches
 
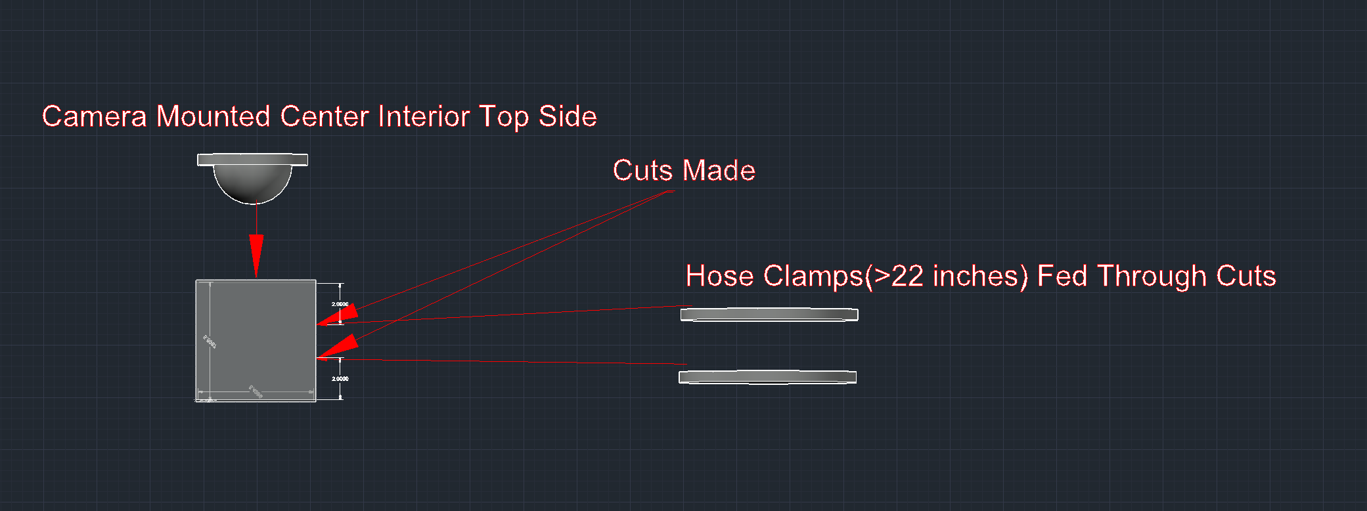
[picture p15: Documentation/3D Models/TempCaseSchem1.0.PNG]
Figure 1. Temporary Casing Model
 
<div align="center"> Figure 1. Physical Sign PDF Schematic (Buildable View 1)
<br />
<div align="left">
 
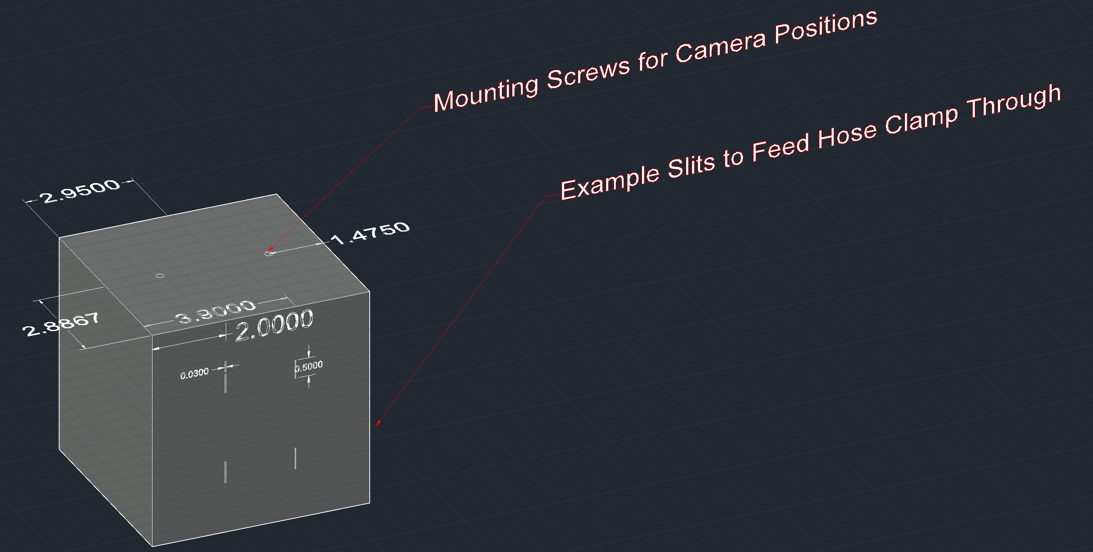
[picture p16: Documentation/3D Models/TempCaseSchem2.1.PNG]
Figure 2. Temporary Casing Model
 
<div align="center"> Figure 2. Physical Sign PDF Schematic (Hose Clamp Hole View)
<br />
<div align="left">
 
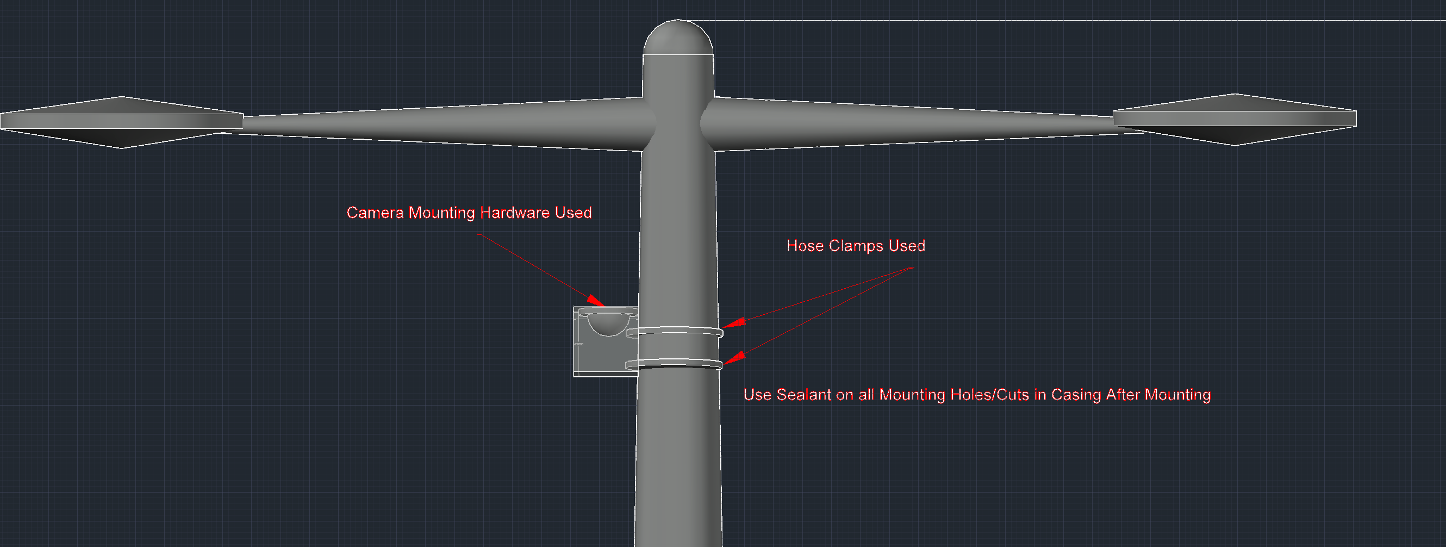
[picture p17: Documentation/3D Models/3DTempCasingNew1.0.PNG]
Figure 3. Temporary Casing Model

<div align="center"> Figure 3. Physical Sign PDF Schematic Final View
<br />
<div align="left">
 
## Mounting Instructions (Reference Figures 1-3)

 1. Camera will be mounted in the center of the top of the acrylic case using the mounting hardware that came with the camera.

 2. Two slits of equal height and 2 to 4 inches apart will then be made on the lower back side wall (2 inches from bottom wall) of the case with the camera pointing outwards for the first hose clamp to be fed through (See Figure 1).

 3. Two more slits will then be made above the slits made in Step 2 (2 inches from top wall).

 4. The hose clamps will then be fed through these slits and tightened onto the light post securing the casing.
Note: Make sure to just snuggly hand tighten any hardware and not overtighten 

 5. After tightened put waterproof sealant over each both mounting screw points and each slit made.

 ## Analysis
 
Dayaanee Clear Acrylic Box with Lid chosen for:
1.     Camera Size 
Necessary dimensions of 5.9 x 5.9 x 5.9 inches due to camera needing at least 5.4 in x 5.4 in x 4.1 in giving a 0.5 in x 0.5 in x 1.8 in tolerance.
 
2.     Clarity
This product has a transparent face and bottom which will suit this application for visibility. 
 
3.     Waterproofing
This box does not claim to be waterproof, but this is not an issue due to waterproofing it being as simple as putting Henkel Clear Silicone Waterproof Sealant on each connecting interior edge [2].
 
4.     Durability
This product is made of acrylic, and acrylic meets the requirements of being able to drill through for mounting the camera and cutting for the hose clamp to feed through[1]. 

5.     Mounting
The mounting hardware provided with the cameras will be used to mount the cameras to the interior top side of the casing.

Henkel Clear Silicone Waterproof Sealant will then be reused to seal any slits made and mounting points.
 
The Steelsoft Hose clamps were chosen due to being:
- Stainless Steel (Weather Resistant)
- Meets the constraint of being at least 22 inches per clamp due to being cuttable to size.

## BOM for Sign Power
| Name of Item | Description | Used in which subsystem(s) | Part Number | Manufacturer | Quantity | Price | Total |
| --- | --- | --- | --- | --- | --- | --- | ----- |
|Dayaanee Clear Acrylic Box with Lid| "Plastic Square Cube Containers with Lid Storage Box 5.9x5.9x5.9 Inches "| Temporary Casing| N/A| Dayaanee| 4| $26.99| $107.96|
|Henkel Clear Silicone Waterproof Sealant| “2.7 oz Tub Clear Silicone Waterproof Sealant, Single Tube”| Temporary Casing| 908570| Henkel| 2| $6.28| $12.56|
|304 Stainless Steel Hose Clamp| 12 FT Metal Strap + 8 Stronger Fasteners, Large Adjustable Worm Gear Band Hose Clamps Screw Clamps Duct Pipe Metal Clamp Strapping| Temporary Casing| B08Y6LSL3R| Steelsoft| 3| $12.99| $38.97|
|Total| | | | Total Components| 7| Total Cost| $159.49|

 ## Revisions

Rev. 1 
- Updated 3D Buildable Schematic to show camera mounted on light pole in temporary casing.
- Updated constraints

Rev. 2 
- Added Mounting info in analysis under durability section
 
Rev. 3
- Added Notes on Schematic for Mounting/removed paragraph on mounting.
 
Rev. 4
- Added Mounting instructions to correlate with Buildable Schematic

Rev. 5
- Added Buildable Schematic Views
- Added information about hose clamps
 
Rev. 6
- Added sealing mounting and cuts info
- Updated Schematics to show width of slits and sealing info
 
## Cited Sources
 
 [1] “Dayaanee Clear Acrylic Box with Lid, Plastic Square Cube Containers with Lid Storage Box 5.9x5.9x5.9 Inches for Candy Pill and Tiny Jewelry, 2 Pack, ”https://www.amazon.com/Acrylic-Plastic-Dayaanee-Containers-5-9x5-9x5-9/dp/B09HK5Q5BK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, amazon.com. 2022.
 
[2] “Henkel 908570 2.7 oz Tub Clear Silicone Waterproof Sealant, Single Tube,” https://www.amazon.com/Loctite-Silicone-Waterproof-2-7-Ounce-908570/dp/B0002BBX3U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, amazon.com. 2022.
 
[3] “304 Stainless Steel Hose Clamp Assortment Kit DIY, Cut-To-Fit 12 FT Metal Strap + 8 Stronger Fasteners, Large Adjustable Worm Gear Band Hose Clamps Screw Clamps Duct Pipe Metal Clamp Strapping,” https://www.amazon.com/STEELSOFT-Assortment-Stronger-Fasteners-Stainless/dp/B08Y6LSL3R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, amazon.com 2022.

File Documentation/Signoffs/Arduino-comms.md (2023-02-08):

# ESP8266 Arduino Shield for WiFi Communication

## Big Picture

The Arduino devices controlling the signs and pressure tube sensors need to be able to connect to WiFi to interact with the server. Arduino devices do not natively have WiFi capabilities and so an outside device needs to be selected in order to allow this communication.

## Requirements
The requirements for this device are:
1. The shield must be able to communicate between the Arduinos and the WiFi network.
2. The shield must be able to establish a reliable and stable wireless connection to the university's WiFi network.
3. The shield must support the proper level of communication for each device, meaning that low levels of data need to be transmitted over the course of a minute. The network consumption of both the pressure tubes and the sign will need no more than 1 kps. Each device will only be receiving a few simple instruction packets (up to about 50 bytes a piece) and the pressure sensors will be sending out a few packets for an integer count.
4. The shield must have low power consumption to efficiently use energy obtained from the batteries charged by the solar panels.
5. The shield must be easily compatible with the Arduino.

## Specifications

1. Shield Type
    * ESP8266 Arduino Shield[1]
2. Network Capabilities
    * Supports 802.11 b/g/n
    * 2.4GHz
    * 9600 bps transmission rate due to the Arduino’s default baud rate. The ESP8266 itself is capable of transmission rates of 115200bps.
3. Security Protocols
    * Supports WEP, WPA/WPA2 PSK/Enterprise
4. Power
    * 3.0-3.6V DC
    * Consumes about 0.3W on average
5. Inputs
    * Supports UART, GPIO, ADC, PWM, I2C, SPI
6. Range
    *100m indoor, 150m outdoor

## Analysis

1. The ESP8266 Arduino shield provides the necessary interface for connecting an Arduino board to the university's WiFi network. The device’s main functionality is WiFi connectivity.
2. The range of the device was determined to be sufficient for the intended use. In typical indoor conditions, the range is estimated to be 100m and in outdoor conditions, it can reach 150m. The necessary range is estimated to be no more than 91 meters.

 The distance measurement between the corner of the parking lot and the building.

3. The shield supports multiple security protocols to ensure a secure connection to the university's WiFi network.
4. The shield’s 9600bps transmission rate allows it to fulfill the 1000 bps transmission rate requirement easily.
5. The shield consumes low power, making it an efficient solution for powering the communication interface.
6. The shield provides multiple inputs, including UART, GPIO, ADC, PWM, I2C, and SPI, which can be used to connect various peripherals to the Arduino board.
7. The device was chosen because it fulfills all of the aforementioned requirements as well as being very cheap ($7.50 a piece on sparkfun.)
8. The device is easy to install, and meant to be placed atop of the Arduino.
Wiring diagram

## Cited Sources

[1] “ESP8266 WiFi Module ,” sparkfun.com, 2023.
[https://cdn.sparkfun.com/assets/f/e/5/6/f/ESP8266ModuleV2.pdf](https://cdn.sparkfun.com/assets/f/e/5/6/f/ESP8266ModuleV2.pdf)

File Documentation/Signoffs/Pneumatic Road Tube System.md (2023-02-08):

# Detailed Design for Pneumatic Road Pressure Tube Subsystem within the Secondary Data Acquisition System

# **Function of the Subsystem**

This secondary data collecting system will count the number of cars departing or entering sectors (1, 2, 4, and 6) of the Bell Hall parking lot. The counting up or down will be accomplished using a differential pressure sensor. The direction that the vehicle is moving will be the determining factor in whether the counter climbs or drops. Direct direction detection will be accomplished by placing two rows of road tubes instead of one. When a car passes over the differential pressure sensor, a signal from the sensor is transmitted to the CPU. The processor will keep track of every vehicle that enters or exits the parking lot and sends wireless data to the server.

**Constraints**

1. Placement of the road tubes

* Figure 1 shows the parking lot sectors and the entry/exit locations to the parking lot.

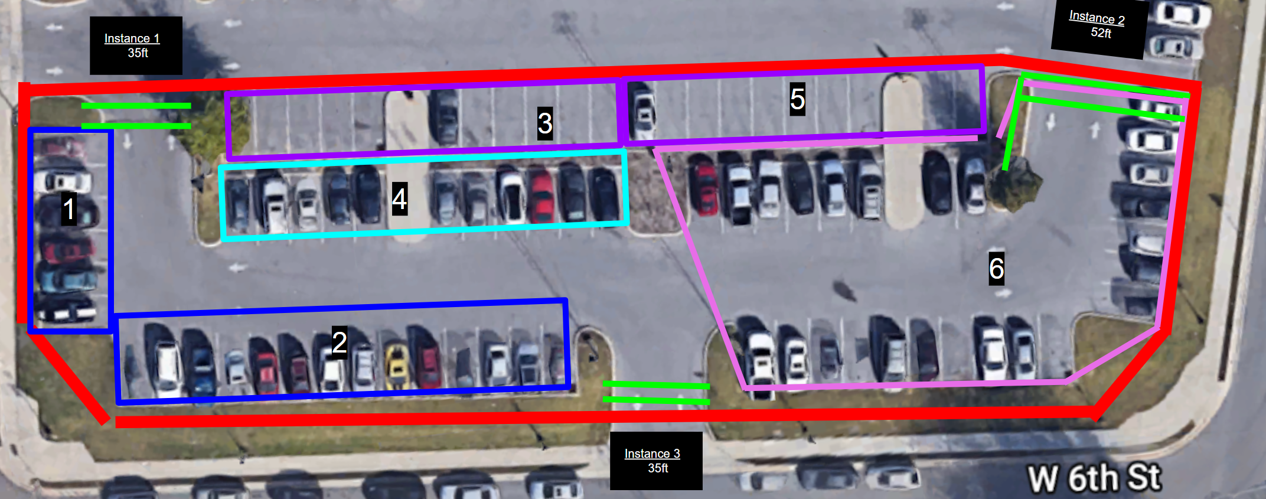
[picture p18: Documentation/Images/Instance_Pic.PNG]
Figure 1. Instance_pic

<div align="center"> Figure 1. Instance_pic
<br />
<div align="left">

        		Figure 1. Parking Lot Sectors and Tube locations/lengths

* The tube placement locations must be on a flat surface and on a straight path.
    * A flat surface is necessary to prevent flapping when a vehicle runs over the road tube, RT-SYN[5],. Flapping could cause the tube to slap down on the pavement and double-count after a vehicle runs over it.
    * A straight path is necessary, so both wheels come in contact with the tube at the same time. Failing to do so could cause double counting due to the tire-to-tube contact point would occur in two separate instances.
2. Vehicle Detection/Direction
* Vehicle detection and direction are critical for the system to operate correctly. Direction is critical to know when the counter must increment or decrement.
3. Mounting/Tying Down Constraints
* Controller case, QL-201510AG[3], must be placed above ground level to prevent flood damage.
* Secure attachment to the mounting surface is necessary to prevent vandalism/theft of the controller case.
    * Worst case for vandalism would be the destruction of the case and its internal components. This could be due to a vehicle running over the case.
* The tube end must be tied down to prevent the tube from moving and remaining in its desired counting location.
4. Maintainability Constraints
* Water protection is necessary to prevent damage to the electrical components inside the system. This involves the casing and any connector that is attached to the case.
* The road tube must be flexible enough, so it doesn’t break whenever a vehicle runs over it.
*  It must also be tough enough to withstand cold/hot climates and UV rays.
    * Coldest temperature recorded in Cookeville, TN : -22 degrees Fahrenheit.
    * Hottest temperature recorded in Cookeville, TN : 105 degrees Fahrenheit.
5. Sensor Constraints
* MPX53DP[8]
    * Burst Pressure - 200kPa or 29 psi
    * Max Pressure - 175kPa or 25.4 psi
    * Pressure Range - (0 - 50kPa) or (0 - 7.25psi)
6.  Processor Constraints
* Arduino Uno Rev3[1]
    * Minimum of 4 Analog input pins
7. Data Transfer Constraints
* ESP8288 Wi-Fi module[2]
    * Wireless transfer of parking lot counter count data to the server.
8. Power Constraints
* 12V DC  is needed to operate the Arduino Board.

**Buildable Schematic**

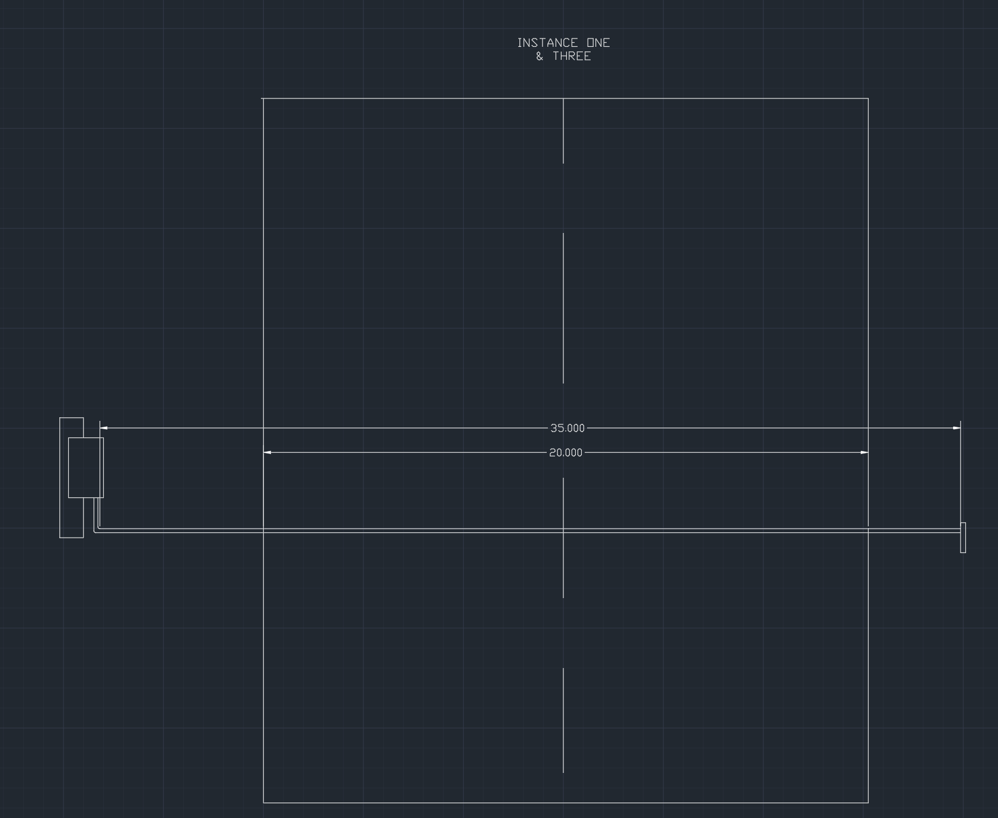
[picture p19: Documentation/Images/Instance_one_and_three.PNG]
Figure 1. Instance_one_three

<div align="center"> Figure 1. Instance_one_three
<br />
<div align="left">

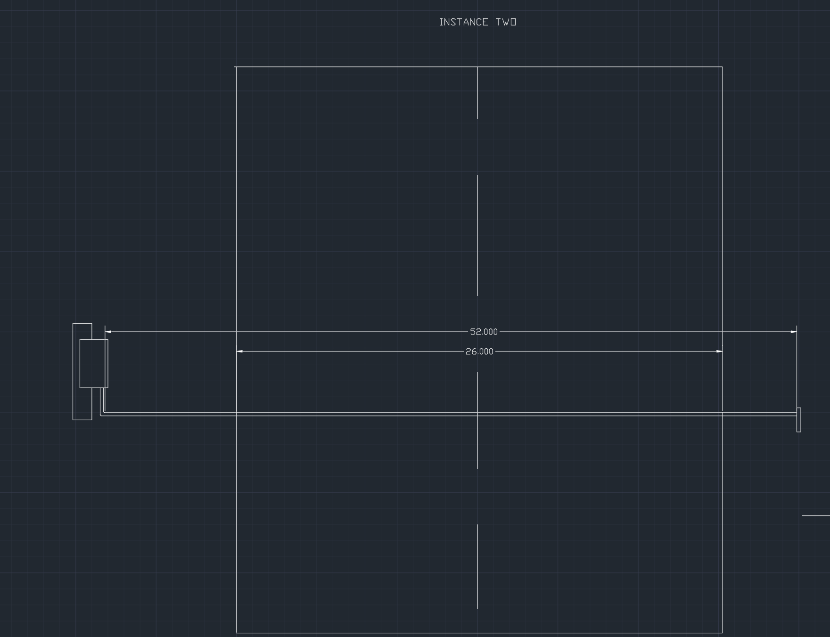
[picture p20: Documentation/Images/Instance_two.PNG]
Figure 1. Instance_two

<div align="center"> Figure 1. Instance_two
<br />
<div align="left">

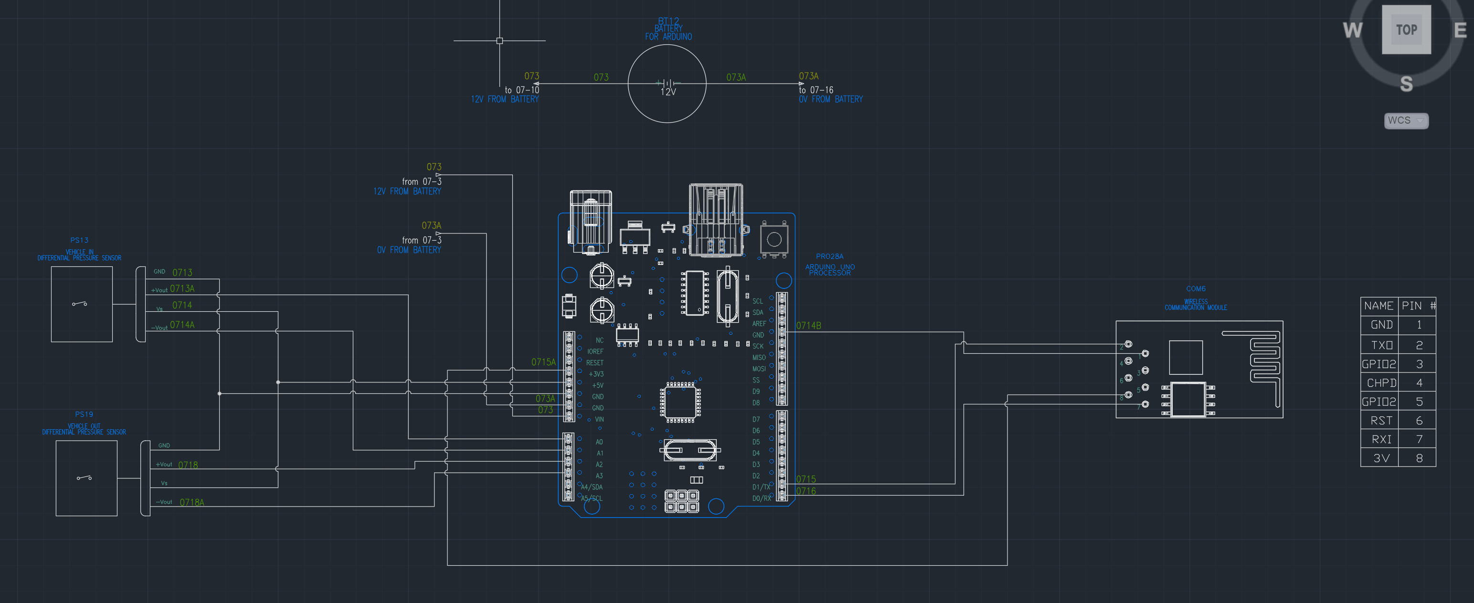
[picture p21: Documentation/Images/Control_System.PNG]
Figure 1. Control_System

<div align="center"> Figure 1. Control_System
<br />
<div align="left">

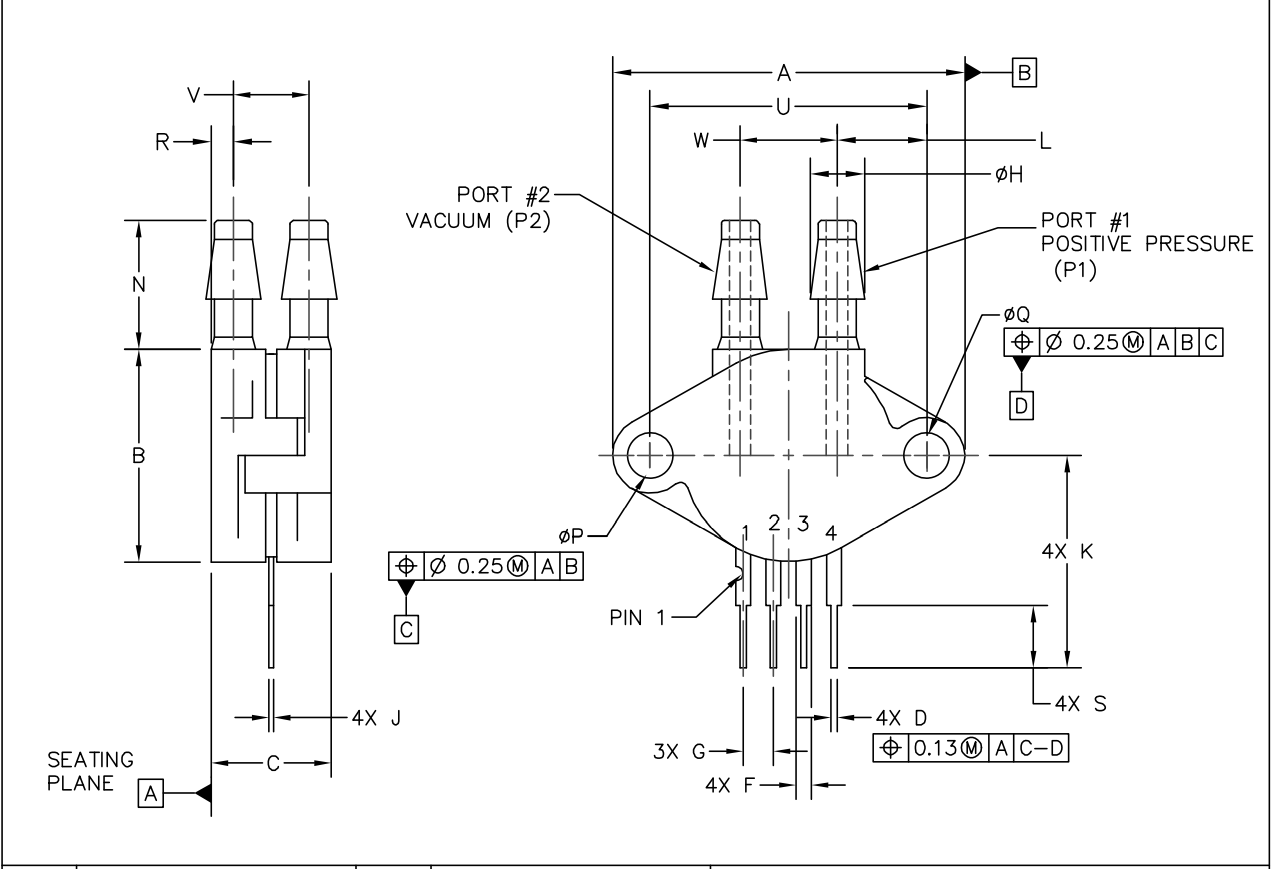
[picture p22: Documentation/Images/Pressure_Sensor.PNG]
Figure 1. Pressure_Sensor

<div align="center"> Figure 1. Pressure_Sensor
<br />
<div align="left">

 **Analysis**

1. Meeting Placement Constraints
    * The road tube will only be put on flat paved areas to fulfill the placement requirements. The placement position will be visually checked to ensure there are no potholes or bumps. Tubes will be situated away from intersections. This allows both wheels to make contact with the tube at the same time, avoiding double counting.
2. Meeting Vehicle Detection/Direction Constraints
    * To fulfill vehicle detection, just one road tube must be laid across the road. However, for direction identification, two tubes must be laid parallel to each other and at least 2-2.5 feet apart. The average automobile tire is 22 inches tall, or somewhat less than 2 feet. This spacing range allows a vehicle to roll over the tubes without colliding with both of them at the same time. The direction will be determined by which tube first delivers a signal from the differential pressure sensor to the CPU.
3. Meeting Mounting/Tying Down Constraints
    * A 3ft tall  2x2 wooden post will be driven into the ground, and the controller case will mount onto it. It’s important to note that the wooden post will be part of the power system design. The case will be mounted one foot above ground level to prevent flood damage. Fasteners will be drilled into the casing/wooden post to attach it. This method is much cheaper than my chain/link method and will have a strong enough hold strength to withstand rough weather conditions.
    * Tying down the end of the tube will be done using a plastic anchor, VORG9089194[6], /hose clamp, 2208004[7], combination. The anchor has a hole where the hose can slip through, and the hose clamp will be secured to the other end. This is a cheap method to tie down the tube. Other professional options include road tape, but this option is too expensive. It has the possibility of the adhesive becoming weak and coming off.
4. Meeting Maintainability Constraints
    * IP67 case, and cable glands, B07ZRHPRP7[4],  will ensure water protection to the system. This is a valid choice due to the price not being excessive.
    * The rubber tubing used is a synthetic blend that is especially utilized in road tube applications because of its flexibility, severe temperature endurance, and UV ray resistance. The tube has a durometer rating of 60. This implies it has the same hardness as a rubber band. This will prevent the tube from cracking when a vehicle runs over it because it is too fragile. The tube has been tested at temperatures ranging from -40 to 212 degrees Fahrenheit. This range is more than adequate for Cookeville's coldest and hottest recorded temperatures. According to NRC.gov, EPDM material is certified A or good up to 100 degrees Fahrenheit, which is an outstanding grade since UV ray exposure will be constant. This tube is not a cheap alternative, but it is required owing to the everyday damage that the tube will get, since lesser solutions may have a shorter lifespan.
5. Meeting Sensor Constraints
    * Pressure Range
        * o   The MX53DP has three pressure specs that are vital to its operation and durability and thus needed to be considered for selecting my pressure sensor. First, burst pressure (P1 >P2) is 200 kPa or 29 PSI; this means that exceeding this pressure would damage the sensor to the point of interoperability. Secondly, max pressure of 175 kPa or 25.4 PSI means the max pressure the sensor can accurately read. Lastly, is the pressure range spec, which is 0 – 50 kPa or 0 – 7.25 PSI. This is the pressure to output voltage range for the sensor.
    * Finding Pressure Specs In my System
        * o   According to Boyle’s Law, the pressure inside a sealed container is dependent on the volume inside the container. I used Boyle’s law and the Ideal Gas Law to deduce the pressure range, my thought process was to find the initial pressure inside the tube if no vehicle was over it. Since air is a gas, I used the Ideal Gas Law to find the initial pressure and the volume of a cylinder formula. My results are shown in the table below. In the table below, I used the average Cookeville weather data I found at [cite(weather-spark)], which is 88 degrees Fahrenheit for the high and 28 degrees Fahrenheit for the low. Instances 1 and 3 have the same tube length thus, the pressure will be the same at all the different “run-over points''. Instance 2 will differ since the tube length will be longer. The “length” tab displays the length in reference to the control box. Ex) Column 4/Row A has a length of 35 ft; this implies that the “run-over” spot will be 35 ft away from the control box. At 88 degrees Fahrenheit, the PSI range in instance 1&2 is 1.5 to 11.3 PSI. The instance 2 range will be 1.4 to 4.58 PSI. At 28 degrees Fahrenheit, the PSI range in instance 1&3 is 0.8 to 6.16 PSI. The instance 2 range will be 0.81 to 2.58 PSI. All of these ranges are in the operating range and are less than 40 percent of my rated max pressure, so temperature deviations won't cause the PSI to exceed the max pressure. 

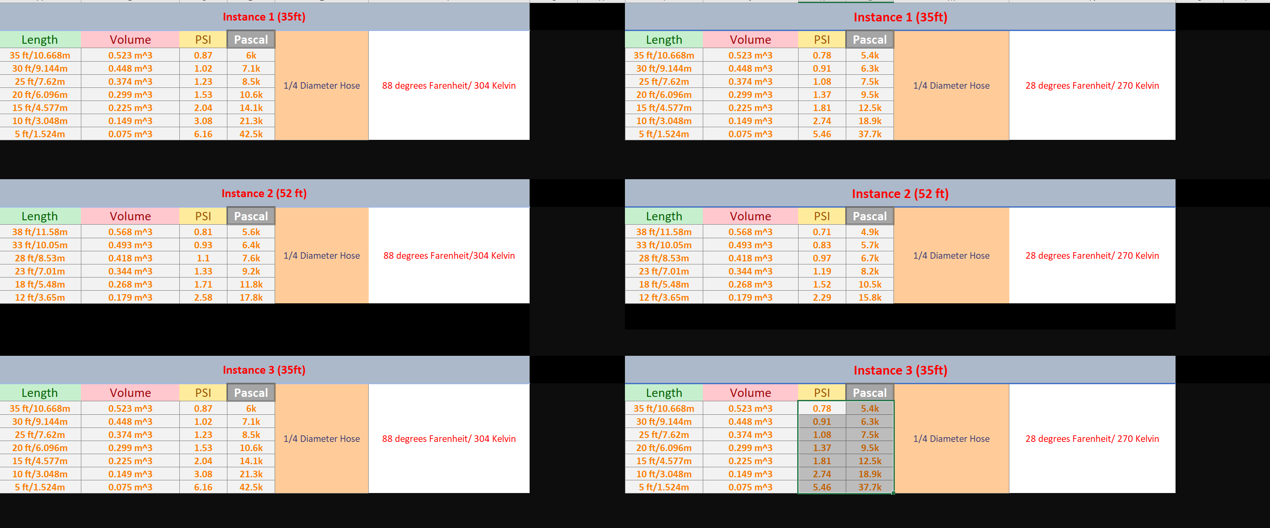
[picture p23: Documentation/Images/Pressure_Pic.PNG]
Figure 1. Pressure_Pic

<div align="center"> Figure 1. Pressure_Pic
<br />
<div align="left">
 			  Fig 2. Pressure calculation table

6. Meeting Processor Constraints
* The Arduino Uno Rev3[1] CPU was selected for this system. This board includes six analog input pins, which is two more than is required for this system and hence meets the limitation. Two analog pins will be required for each pressure sensor in each system.
7.  Meeting Data Transfer Constraints
* The ESP8288 Wi-Fi module[2] was chosen as the connectivity module for this system. This module is part of the communications subsystem, however, it will allow wireless connectivity to the server through wi-fi. The counter tally will be received by the module from the Arduino board and wirelessly sent to the server.
8. Meeting Power Constraints
* The power supplied to the system will be part of a separate subsystem, and it will be the necessary 12V DC to power the board.
9. Potential Issues
* The post/mounting is not the most secure method. However, it is a cheap method that should prove sufficient for a proof of concept. Any vandalism or damage caused to the system will be considered an acceptable risk. 
* Even though the tubes selected are specifically used for pneumatic road tube applications, they are not indestructible. Due to the daily abuse, they will be receiving, they are susceptible to being damaged. This could potentially be an expensive maintenance issue but will be considered an acceptable risk. 
7. BOM

## Bill of Materials

| Name of Item | Description | Used in which subsystem(s) | Part Number | Manufacturer | Quantity | Unit Price | Total |
| --- | --- | --- | --- | --- | --- | --- | ----- |
| Arduino Uno REV3 | Microprocessor, 14 digital I/O pins, 6 analog inputs | Secondary Acquisition System | A000066 | Arduino | 3 | $27.60 | $82.80 |
| Differential Pressure Sensor | Pressure Sensor 7.25PSI (50kPa) Differential Male - 0.19" (4.93mm) Tube, Dual 0 mV ~ 60 mV (3V) 4-SIP Module | Secondary Acquisition System | MPX53DP-ND | NXP USA Inc. | 6 | $18.92 | $113.52 |
| Road Tube | 1/4 x 9/16 OD Round-Synthetic 100' | Secondary Acquisition System | RT-SYN | Diamond Traffic Products | 3 | $117.00 | $351.00 |
| Ground Stake | 11 inch long, ⅝ diameter hole | Secondary Acquisition System | VORG9089194 | Lehigh | 6 | $2.22 | $13.32 |
| Road Tube End Plug | Allen head plug for road tube | Secondary Acquisition System | 1002119 | Lancer | 6 | $0.76 | $4.56 |
| Hose Clamp  | Steel hose clamp, ¼” - ⅝” size range | Secondary Acquisition System | 2208004 | Qilipsu | 10 | $0.63 | $6.30 |
| Cable Gland | Weatherproof IP68 adjustable locknut for 13-18 mm cable diameter | Secondary Acquisition System | B07ZRHPRP7 | Qilipsu | 1 | $10.99 | $10.99 |
| Junction box | IP67 waterproof enclosure, (7.9"x5.9"x3.9")
| Secondary Acquisition System | QL-201510AG | Qilipsu | 3 | $18.99 | $59.97 |
| ESP8266 | 4MB flash, wifi module | Secondary Acquisition System | WRL-17146 | Spark Fun | 3 | $7.50 | $22.50 |
|Total|	| | | Total Components| 41| Total Cost| $664.96|

Cited Sources

1. “Arduino Uno REV3.” _Arduino Online Shop_, https://store-usa.arduino.cc/products/arduino-uno-rev3.
2. #1758620, Member. “WIFI Module - ESP8266 (4MB Flash).” _WRL-17146 - SparkFun Electronics_, https://www.sparkfun.com/products/17146.
3. _Qilipsu Junction Box with Mounting Plate 110X80X70MM, ABS ... - Amazon.com_. https://www.amazon.com/QILIPSU-Electrical-Waterproof-Dustproof-Enclosure/dp/B08PP6VYCF.
4. _QILIPSU 3/4 NPT Nylon Cable Gland, Waterproof IP68 Adjustable Locknut ..._ https://www.amazon.com/QILIPSU-Waterproof-Adjustable-Locknut-Diameter/dp/B07ZRHPRP7. 
5. “EPDM Synthetic Road Tube.” _EPDM Synthetic Road Tube | Diamond Traffic ProductsRT-SYN_, https://diamondtraffic.com/product/EPDM-Road-Tube.
6. “Lehigh GS11 Ground Stake, 11 in L, 5/8 in W, Plastic.” _Shell Lumber and Hardware_, https://www.shelllumber.com/lehigh-group-gs11-stake-ground-orange-11in.html.
7. _1/4"- 5/8" #4 Stainless Steel Hose CLAMP W/ Carbon Screw - Supplyhouse.com_. https://www.supplyhouse.com/Wal-rich-2208004-1-4-5-8-4-Stainless-Steel-Hose-Clamp-w-Carbon-Screw.
8. “MPX53DP: Digi-Key Electronics.” _Digi_, https://www.digikey.com/en/products/detail/nxp-usa-inc/mpx53dp/951812. 
9. _Chemical Resistance and Chemical Applications for CPVC Pipe and Fittings._ https://www.nrc.gov/docs/ML1820/ML18207A604.pdf.

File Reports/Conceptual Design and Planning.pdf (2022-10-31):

# Conceptual Design and Planning for Parking Lot Monitoring System

Regulo Garza, Gabriel Laboy, Kester Nucum, Genevieve Schreiber, Aaron Wilhite
Department of Electrical and Computer Engineering Tennessee Technological University Cookeville, TN
rgarza42@tntech.edu, gmlaboy42@tntech.edu, knucum42@tntech.edu, gschreibe42@tntech.edu, awwilhite42@tntech.edu
I. INTRODUCTION
The goals of this conceptual design document are to expand upon the fully formulated problem surrounding a parking lot monitoring system to be implemented on the campus of Tennessee Technological University, the fully decomposed conceptual solution, the constraints on the solution and sources of constraints, the analytic validation of the constraints, and an optimal detail design schedule. The conceptual design of the parking lot monitoring system breaks down the concept of a parking lot monitoring system into subsystems that perform tasks to meet the specifications from the customer and other stakeholders while also satisfying the constraints generated from customer specifications, engineering standards, ethical concerns, broader implications, etc. The conceptual design informs the detailed design since the conceptual design provides the “what’s” that the system must accomplish, so that the detailed design can address the “how’s” (i.e. technology and components) to perform the “what’s” from the conceptual design.
A. Fully Formulated Problem
The parking lot monitoring system shall collect data and provide information regarding parking spot availability to students. The conceptual design for the parking lot monitoring system consists of five major subsystems: counting sensors, ground truth sensors, a server, a mobile application, and a sign (Figure 1). The system functional expectations and constraints (demarcated by SC.x, with SC standing for “System Constraint” and x being the specific alphabetic letter) include:
(a) System shall not obstruct any parking spots on campus in a way that would not allow a person to park in a given spot.
- This constraint was explicitly requested by the customer NAVSEA as a major requirement and echoed later by the Tennessee Tech Parking and Transportation Office, a stakeholder.
(b) System shall not interfere with parking traffic on campus in a way that would cause traffic to worsen.
- This constraint was explicitly requested by the customer NAVSEA as well as another major stakeholder, the Tennessee Tech Parking and Transportation Office.
(c) System shall not permanently store images.
- This constraint was explicitly defined by a major stakeholder, the Tennessee Tech University Police, to avoid any security cameras being used in the design. Security cameras fall under the jurisdiction of the University Police, so if camera technology is utilized, they must not have image storing capabilities.
(d) System shall not record videos.
- This constraint was explicitly defined by a major stakeholder, the Tennessee Tech University Police, for the same reasons as outlined in SS.c. If camera technology is utilized, they must not have video recording capabilities.
(e) System shall operate during Red Zone parking enforcement hours of 7:30 a.m. - 4:30 p.m. on Mondays through Fridays.
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

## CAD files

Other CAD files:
Documentation/Poster/Poster Template/Images/INN_Topology.dwg

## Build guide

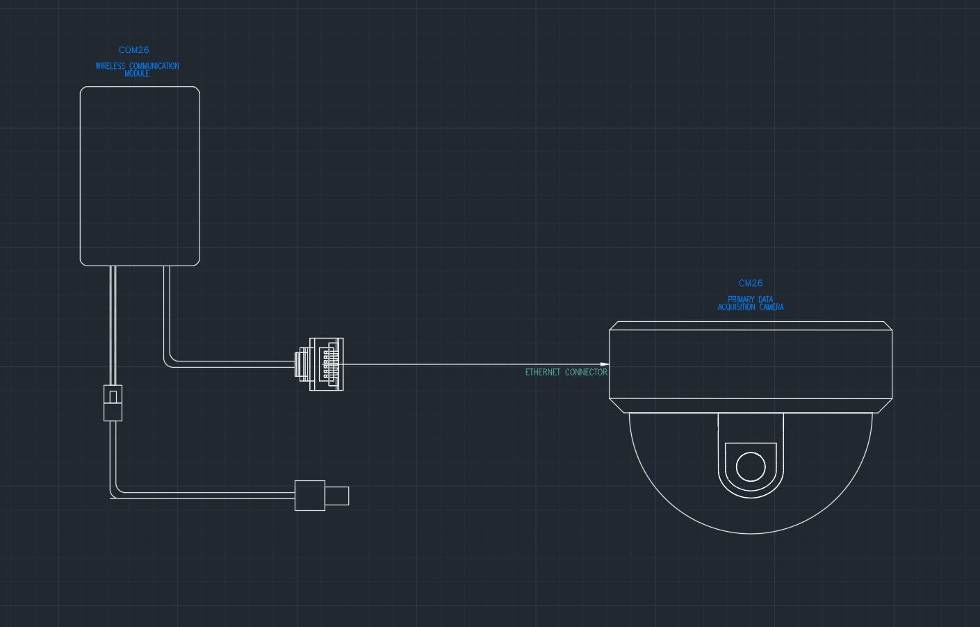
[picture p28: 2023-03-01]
Documentation/Electrical/Schematics/Camera_Comms_Wiring.png

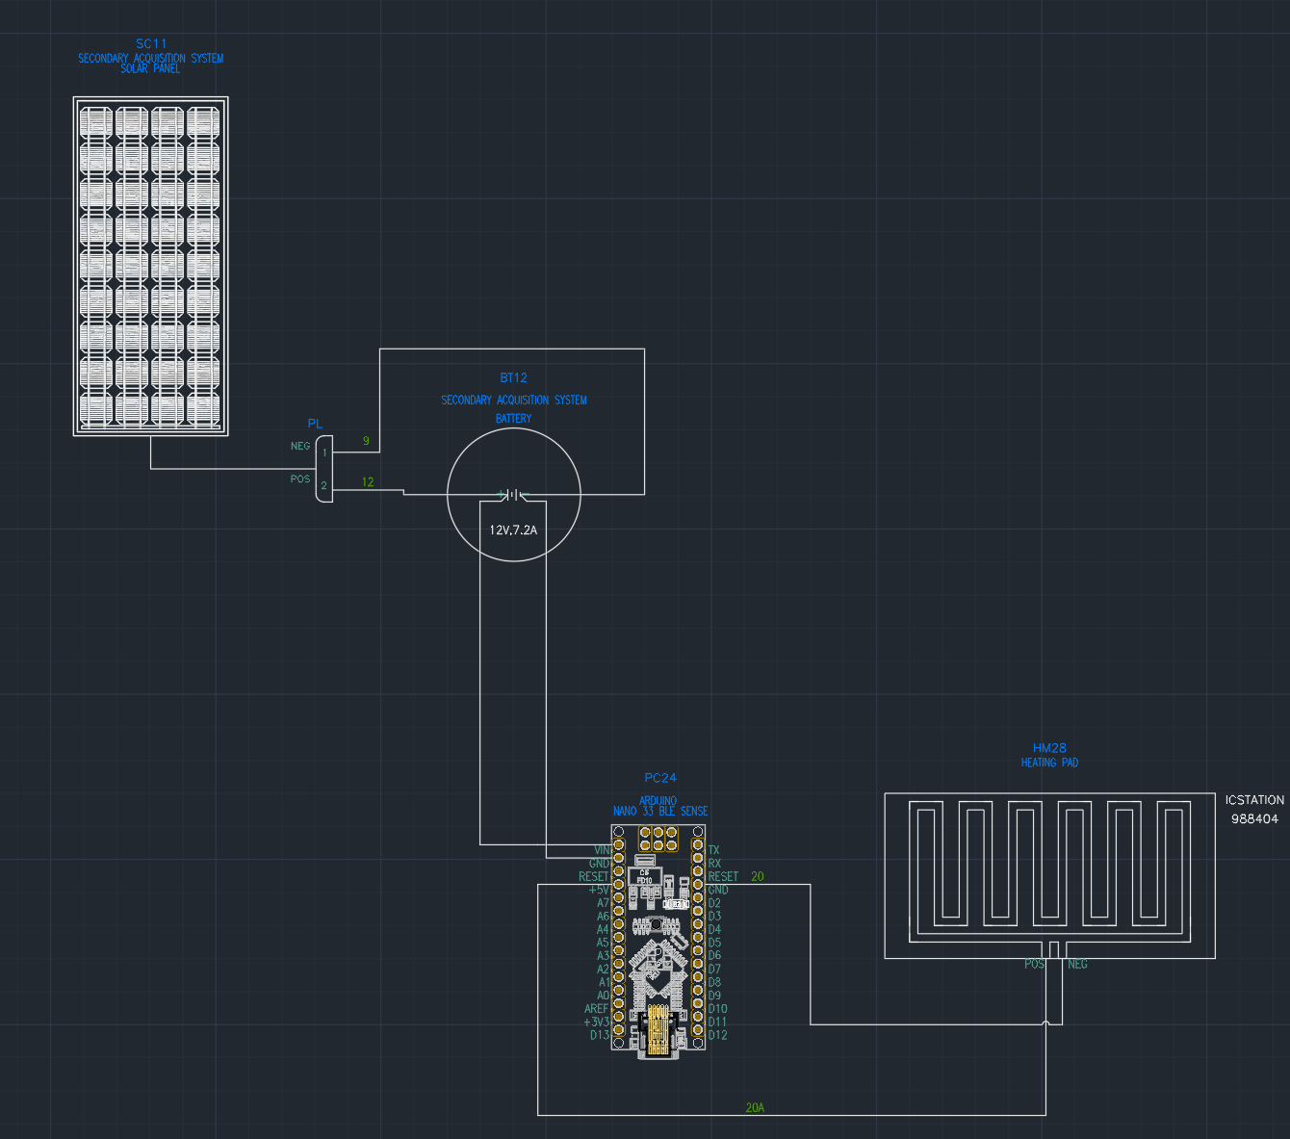
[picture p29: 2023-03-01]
Documentation/Electrical/Schematics/Heat_Module_Wiring.png

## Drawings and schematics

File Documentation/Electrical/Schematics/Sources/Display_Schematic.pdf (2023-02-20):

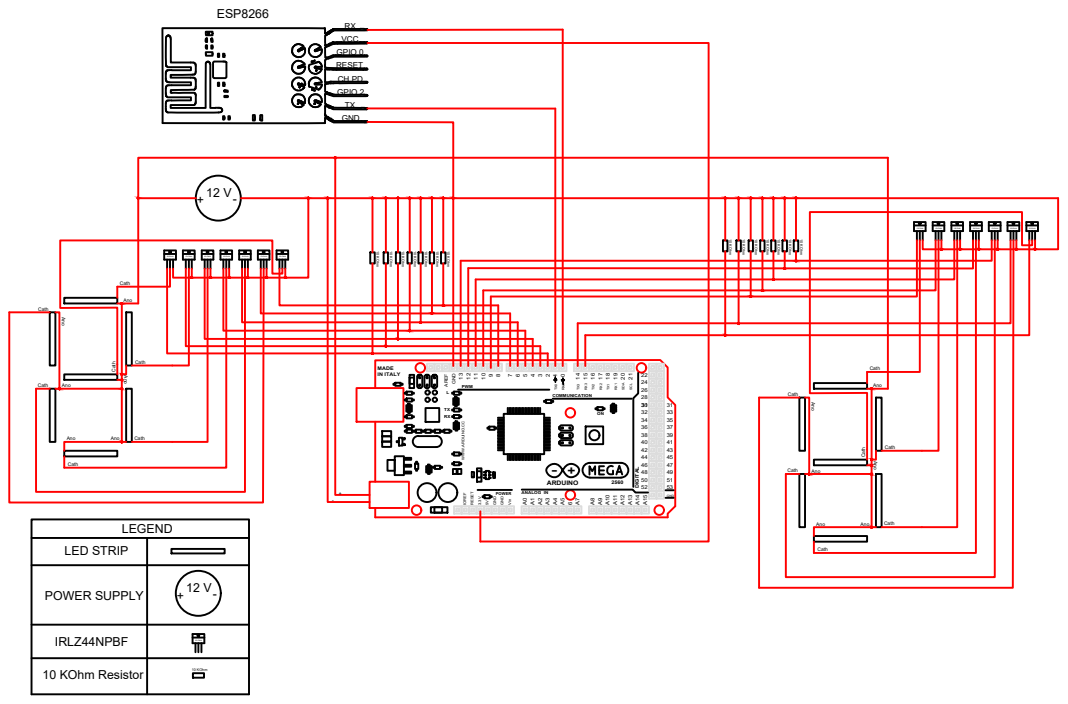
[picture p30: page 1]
- IRLZ44N; IRLZ44N; IRLZ44N Cath Ano AnoAno; Ano; Cath Cath Cath; DIGITAL 31 313335373941434547495153 30323436384042444648505222242628 GND; TX3 RX3 TX2 RX2 TX1 RX1 SDA; SCL 10; AREF PWM; A0A1A2A3A4A56A7A8A9A10 A11 A12 A13 A14 A15 TXRXL; IOREF RESET; 5VGND GND; 10 KOhm

Vin + - RX VCC GPIO 0 RESET CH PD GPIO 2 TX GND ESP8266 LEGEND LED STRIP 12 V POWER SUPPLY + -

10 KOhm IRLZ44N 10 KOhm IRLZ44NPBF 10 KOhm Resistor

Cath Cath Cath Ano

Ano Cath Ano AnoAno Ano Cath Cath Cath

WWW.ARDUINO.CC ON MADE IN ITALY

Ano POWER ANALOG IN COMMUNICATION ARDUINO 2560 - +

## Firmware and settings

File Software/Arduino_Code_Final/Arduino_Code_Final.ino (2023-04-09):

const int onesDigitPins[] = {2, 3, 4, 5, 6, 7, 8};
const int tensDigitPins[] = {9, 10, 11, 12, 13, 14, 15};

// Seven segment binary codes for 0 through 9
const int digitCodes[] = {
  0b00111111, // 0
  0b00000110, // 1
  0b01011011, // 2
  0b01001111, // 3
  0b01100110, // 4
  0b01101101, // 5
  0b01111101, // 6
  0b00000111, // 7
  0b01111111, // 8
  0b01101111  // 9
};

int data; // Stores number to display to sign

void setup() {
  // Set digit pins as outputs
  for (int i = 2; i <= 15; i++) {
    pinMode(i, OUTPUT);
  }
  
  // Setup serial connection
  Serial.begin(9600);
  //Serial.setTimeout(3);
}

// Main loop
void loop() {
  // Constantly update sign with number coming from computer
  while (!Serial.available());
  data = Serial.readString().toInt(); 
  displayNumber(data);
}

// Separate parking lot number into two separate values
void displayNumber(int number) {
  // If number is outside of range, return
  if (number < 0 || number > 99) {
    return;
  }
  
  int onesDigit = number % 10;
  int tensDigit = number / 10;
  displayDigit(onesDigit, onesDigitPins);
  displayDigit(tensDigit, tensDigitPins);
}

// Write to correct pins to output to correct LED strips based off digit value
void displayDigit(int digit, const int* digitPins) {
  // If digit is outside of range, return
  if (digit < 0 || digit > 9) {
    return;
  }

  digitalWrite(digitPins[0], digitCodes[digit] & 0b00000001);
  digitalWrite(digitPins[1], digitCodes[digit] & 0b00000010);
  digitalWrite(digitPins[2], digitCodes[digit] & 0b00000100);
  digitalWrite(digitPins[3], digitCodes[digit] & 0b00001000);
  digitalWrite(digitPins[4], digitCodes[digit] & 0b00010000);
  digitalWrite(digitPins[5], digitCodes[digit] & 0b00100000);
  digitalWrite(digitPins[6], digitCodes[digit] & 0b01000000);
} 

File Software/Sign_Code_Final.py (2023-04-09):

# Import Libraries
import serial
import time
import firebase_admin
from firebase_admin import credentials
from firebase_admin import firestore

# Initialize serial communication of Arduino
arduino = serial.Serial(port='COM4', baudrate=9600)

# This function returns available parking lot count from firebase database
def getData():
    try:
        app = firebase_admin.get_app()
        firebase_admin.delete_app(app)
    except:
        pass

    # Load credentials and access firebase database
    cred = credentials.Certificate('intelligentparkingfb-59ed35520e29.json')
    app = firebase_admin.initialize_app(cred)
    db = firestore.client()

    # Access table containing parking lot counts
    doc = db.collection(u'parkingLots').document(u'92opt')

    firebase_data = doc.get().to_dict()['openSpots']
    print("Open Spots:",firebase_data)
    return firebase_data

# This function sends data to Arduino
def writeData(input_data):
    arduino.write(bytes(str(input_data), 'utf-8'))
    time.sleep(0.05)
    
# Main loop
while True:
    data = getData()
    writeData(data)
    time.sleep(15)

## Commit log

2022-11-10 Added markdown file for camera subsystem
2022-11-10 Added three images used in camera signoff
2022-11-10 Updated detailed design sign off for cameras
2022-11-10 Added BOM to cameras sign off
2022-11-20 Added BOM to Sign Signoff
2022-11-22 Create Pneumatic Road Tube System.md
2022-11-23 Updated Camera Signoff markdown to address needed comments and to adapt to new cameras
2022-11-23 Added schematics for new cameras and positioning on lightposts
2022-11-23 Added Bell Hall Lot parking spaces image for cameras signoff
2022-11-23 Added sectors image for Bell Hall Lot for cameras signoff
2022-11-23 Added Bell Hall Lot sector analysis image for cameras signoff
2022-11-28 Fixed some bullet points in Markdown for camera signoff
2022-11-30 Uploaded corrected Bell Hall Lot Sectors Analysis image
2022-11-30 Updated signoff for cameras to address new comments on formatting and new constraints/analysis
2022-11-30 Added left off text in camera signoff markdown
2022-11-30 Addressed Added more discussion on data transmission/obtainability and dynamically tracked parking spot constraints for Cameras Signoff
2022-11-30 Fixed formatting issues in Cameras Signoff
2022-11-30 Fixed broken image links in cameras signoff
2022-11-30 Updated Readme's and markdowns to new template
    [INN_Topology.dwg]
2022-12-01 Finished repository main readme, customized and streamlined it for our repo
    [INN_Topology.dwg]
2022-12-02 Added minimum frame rate constraints and considerations to cameras signoff
2022-12-05 Addressed frame rate constraints in camera detailed design
2022-12-08 Heat Module for Primary Data Acquisition Sign-off
2022-12-22 Display Schematic Added
2022-12-27 Add 3D Model of Sign
    [Sign Buildable Schematic.dwg]
2022-12-27 Add Display Schematic
2023-02-01 Create cammera_comms
    Camera communications signoff
2023-02-02 Update Pneumatic Road Tube System.md
2023-02-05 Add V2nd View of 3D Schematic
    Shows view of 3D schematic with mounted weatherproof case
2023-02-06 Update Temp Casing Buildable Schematic
2023-02-06 Update Temp Casing Schematic
2023-02-10 Update 3D Model to Show Mounting
2023-02-10 Update Sign.md
    - Redefined LED visibility constraints and analysis
    - Clarified transistor constraints, specs, and analysis
2023-02-15 Reformatted camera comm signoff (still to be finished)
2023-02-16 Completed camera communications detailed design
2023-02-16 Add Camera Communication 3D Schematic
2023-02-16 Fixed some formatting for camera comms signoff
2023-02-16 Detail Design for PDA Heat Module
2023-03-21 Re-added camera detailed design, which disappeared somehow
2023-03-21 Added readme for for prototype specifications and substitutions
2023-03-29 Updated prototype substitution
